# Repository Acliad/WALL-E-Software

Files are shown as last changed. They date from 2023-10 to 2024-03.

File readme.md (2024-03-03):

# Overview
This repo contains code, PCB files, and some 3D files for a WALL-E robot. The robot is controlled by an ESP32 microcontroller with PlayStation Navigation controllers. 3D files can be found under the `Mechanical` folder. The PCB files can be found under the `PCB Files`. The code can be found under the `src` folder. 

This readme file contains information on setting up and using WALL-E, and there are several videos in the `Docs` folder that give examples.

The code is written as an Arduino sketch, but has many C++ files and classes. The custom library code is located in the `src` folder of the walle sketch and is organized into the following folders:
- `audio`: Contains the code for the audio player.
- `display`: Contains the code for the display and animations.
- `motion`: Contains the code for the motion animations.
- `button`: Contains the code for the button handling.
- `controller`: Contains the code for the controller handling.
- `stats`: Contains a simple stats class mostly used for debugging.

Additionally, the root of the `src` folder contains the main sketch file, `walle.ino`, which is the entry point for the program. It also contains several files to help configure WALL-E:
- `config.hpp`: Contains the configuration for the audio player, display, and controller.
- `display_animations.hpp` and `display_animations.cpp`: Contains code for programatically defining display animations.
- `motion_animations.hpp` and `motion_animations.cpp`: Contains code for programatically defining motion animations.

# Button Mapping
This image can be found in `Docs/Images`.

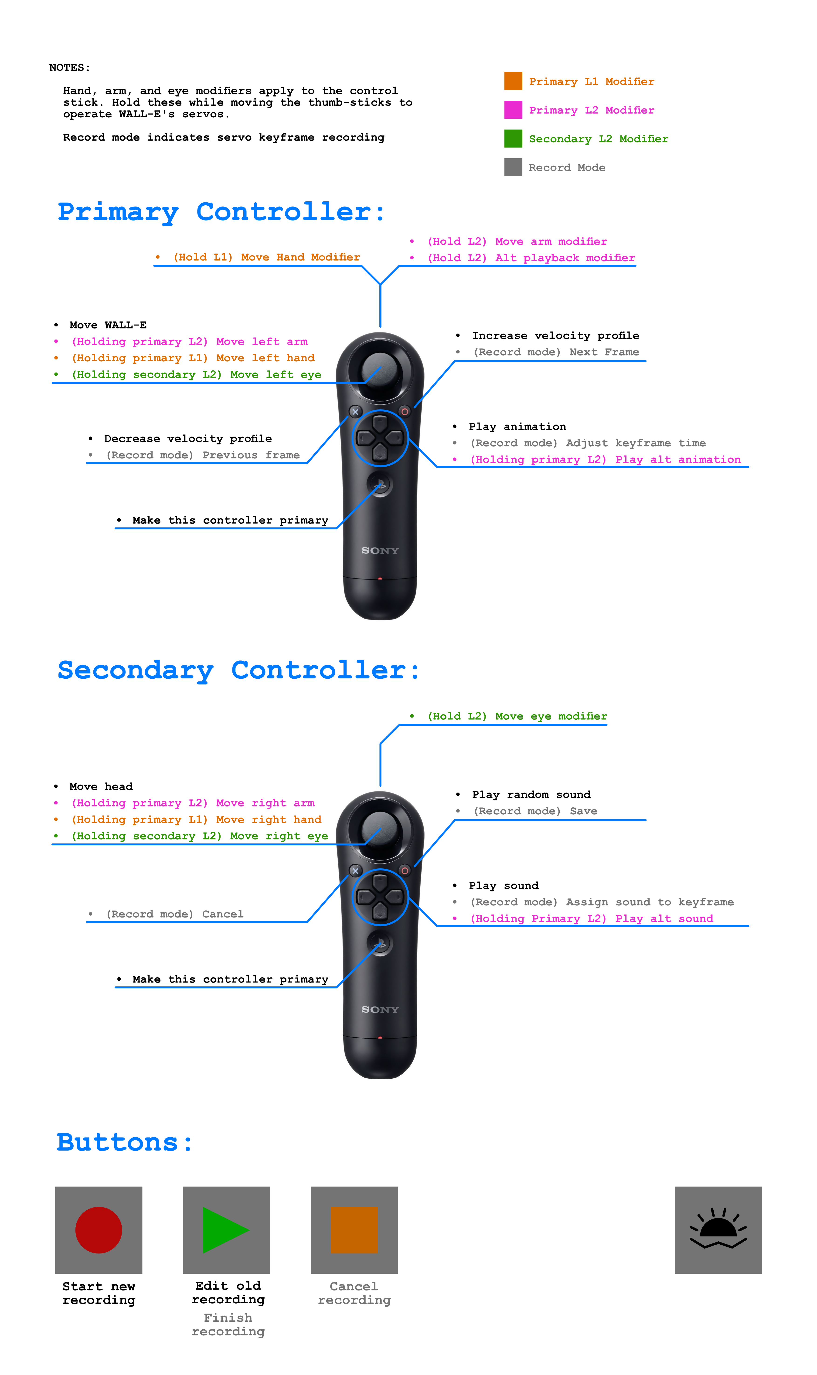
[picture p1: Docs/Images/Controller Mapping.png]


# Setting up Arduino IDE
This project uses a special board package for the ESP32 called [Bluepad32](https://github.com/ricardoquesada/bluepad32). To install it, you need to add this board to your Arduino IDE. The abreviated steps to do this are below. See [this doc page](https://bluepad32.readthedocs.io/en/latest/plat_arduino/) for more detailed instructions.
1. Open the Arduino IDE settings and add the following two URLs to the "Additional Boards Manager URLs" field: 
`https://raw.githubusercontent.com/espressif/arduino-esp32/gh-pages/package_esp32_index.json`
`https://raw.githubusercontent.com/ricardoquesada/esp32-arduino-lib-builder/master/bluepad32_files/package_esp32_bluepad32_index.json`
2. Install the ESP32 and ESP32 Bluepad32 boards from the Boards Manager.
3. Select the `ESP32-WROOM-DA Module` from the Tools > Board > esp32_bluepad32 menu.

You will also need to install the following libraries:
- Adafruit PWM Servo Driver Library
- DFPlayer Mini Mp3 by Makuna
- Ramp
- ServoESP32
- TFT_eSPI

You will need to setup the TFT_eSPI library with the correct config. To do this, create a `TFT_eSPI_Setups` folder in your Arduino libraries folder (usualy in `~/Documents/Arduino/libraries/`), then copy the `TFT_eSPI_walle_setup.h` file in `src/display/` to this new folder. After that, open User_Setup_Select.h in the `/TFT_eSPI/` library folder and comment out the current user config (`User_Setup.h` by default), then add the following line:
```cpp
 #include <../TFT_eSPI_Setups/TFT_eSPI_walle_setup.h>
 ```

After this, you should be able to compile and upload the code to the ESP32. Make sure WALL-E is powered on before plugging in the USB cable to the ESP32, otherwise the USB port will attempt to power the servo motors and will likely trip your USB port's overcurrent protection.

Note that the Arduino IDE will throw some warnings related to "converting a string constant to 'char*'" as well as some bluepad and eSPI_TFT warnings. These can be ignored.

# Adding new sounds
New sounds can be added to the audio player's SD card as `.mp3` files. Audio tracks must be labeled as numbers with the format `0001.mp3`, `0002.mp3`, etc. The number of the audio track is the index that will be used to play the sound. You can configure the audio player sounds and keybindings in the `config.hpp` file. Here is what the folder structure on the SD card should look like:

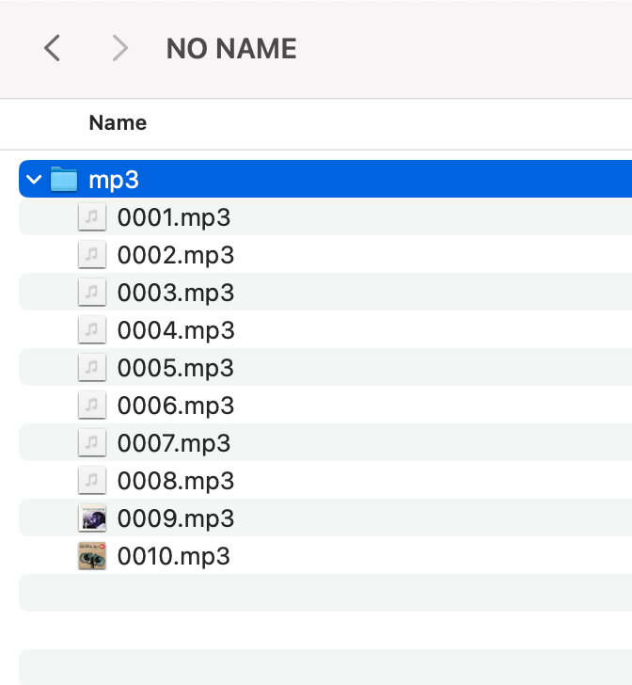
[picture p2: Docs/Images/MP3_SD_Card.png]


For instance, if you add a track `0011.mp3` and you wish to bind it to the `L2 + Up` button, you would add the following line to the `config.hpp` file:
```cpp
const int audio_track_selection_list[] = {
    TRACK_INDEX_EVE_1, // Up
    TRACK_INDEX_TADA, // Right
    TRACK_INDEX_SCREAM, // Down
    TRACK_INDEX_WALLE_1, // Left
    11, // L2 + Up <<<<<<<<<<<<<<<<<<<<<<<< CHANGED TRACK 
    TRACK_INDEX_EVE_3, // L2 + Right
    TRACK_DEFINE_DANCING, // L2 + Down
    TRACK_LA_VIE_EN_ROSE, // L2 + Left
};
```

Sounds which are bound to a button can be added to keyframes in motion animations. 

Similarly, you could add it to the audio_track_random_list. 

```cpp
// Tracks in this array will be selected randomly by the playRandomTrack() function
const int audio_track_random_list[] = {
    TRACK_INDEX_EVE_1,
    TRACK_INDEX_EVE_2,
    TRACK_INDEX_EVE_3,
    TRACK_INDEX_WALLE_1,
    TRACK_INDEX_SCREAM,
    TRACK_INDEX_TADA,
    11 // <<<<<<<<<<<<<<<<<<<<<<<< ADDED TRACK
};
```

# Adding solar animations
The steps to add a solar animation are as follows:
1. Declare your variable name in display_animations.hpp:
```cpp
extern AnimateLeve animate_display_startup;
...
// Add your variable name here
extern AnimateLevel my_animation;
```
2. Define your vairable in display_animations.cpp:
```cpp
AnimateLevel animate_display_startup = AnimateLevel();
...
// Define your variable here
AnimateLevel my_animation = AnimateLevel();
```
3. Create a setup_my_animation() function in display_animations.cpp:
```cpp
void setup_my_animation() {
  my_animation.addKeyframe(0, 0);
  my_animation.addKeyframe(1000, 1);
  ...
}
```
4. Add your setup_my_animation() function to the setup_animations() function in display_animations.cpp:
```cpp
void setup_animations() {
  setup_startup();
  ...
  // Add your setup_my_animation() function here
  setup_my_animation();
}
```

Now your variable ```my_animation``` will be available to use in the main sketch. 

### Notes
- A keyframe with a single change will perform that change at the beginning of the keyframe. For example, if 2 bars are on and you request 3 to be on with a duration of 1 second, the 3rd bar will turn on immediately and the keyframe will wait for 1 second to complete. If you have two or more changes in a keyframe, the changes will be evenly distributed throughout the duration of the keyframe, ending with a change. For example, if 2 bars are on and you request 5 to be on with a duration of 1 second, the 3rd bar will turn on immediately, the 4th bar will turn on after 0.5 seconds, and the 5th bar will turn on after 1 second.
- The sun's status is always evaluated at the beginning of a keyframe.

# Adding motion animations
The steps to add a motion animation are as follows:
1. Declare your variable name in motion_animations.hpp:
```cpp
namespace MotionAnimations {
    // Add custom animations here:
    extern ServoAnimation my_animation;

    // Rest of namespace ...
}
```
2. Define your vairable in motion_animations.cpp:
```cpp
namespace MotionAnimations {
    // Define new animations here

    ServoAnimation my_animation = ServoAnimation();

    // Rest of namespace ...
}
```
3. Create a setup_my_animation() function in motion_animations.cpp. Keyframes are created one at a time and then added to the previously created animation. Create a keyframe with `ServoKeyframe *my_keyframe = new ServoKeyframe(duration_ms);`. Add the servo positions to the keyframe with `my_keyframe->add_servo_scaler(servo_ptr, position);`. Add the keyframe to the animation with `my_animation.addKeyframe(my_keyframe);`. Servos are addressed by their name. There is a #define for each servo. E.g, to get the left eye servo you would use `servos.map[SERVO_EYE_LEFT_NAME]` For example:
```cpp
// Create setup functions for each animation.
// NOTE: Don't forget to call these functions in setup_animations().
void setup_my_animation() {
    // Rotate eyes in opposite directions
    ServoKeyframe *my_keyframe1 = new ServoKeyframe(1000);
    my_keyframe->add_servo_scaler(servos.map[SERVO_EYE_LEFT_NAME], 0.75);
    my_keyframe->add_servo_scaler(servos.map[SERVO_EYE_RIGHT_NAME], -0.75);
    
    // Pause for 3 seconds
    ServoKeyframe *my_keyframe2 = new ServoKeyframe(3000);

    // Return the eyes to their original position
    ServoKeyframe *my_keyframe3 = new ServoKeyframe(1000);
    my_keyframe->add_servo_scaler(servos.map[SERVO_EYE_LEFT_NAME], 0);
    my_keyframe->add_servo_scaler(servos.map[SERVO_EYE_RIGHT_NAME], 0);

    // Add the keyframes to the animation
    my_animation.add_keyframe(my_keyframe1);
    my_animation.add_keyframe(my_keyframe2);
    my_animation.add_keyframe(my_keyframe3);
}
```
4. Add your setup_my_animation() function to the setup_animations() function in motion_animations.cpp:
```cpp
void setup_animations(ServoContext servos) {
    // This function should get called in the main setup() function. It calls all animation setup functions for use in
    // the main sketch.

    // Add setup functions for new animations here
    setup_my_animation();

    // Rest of animation setups...
}
```
5. Play the animation with `servo_player.play(&MotionAnimations::my_animation);`. Alternatively, you can add the animation to the `head_animations` array in the main sketch to bind it to a button press:
```cpp
ServoAnimation         *head_animations[] = {
    &MotionAnimations::my_animation, // Up
    nullptr,      // Right
    nullptr,      // Down
    nullptr,      // Left
    nullptr,      // L2 + Up
    nullptr,      // L2 + Right
    nullptr,      // L2 + Down
    nullptr       // L2 + Left
};
```

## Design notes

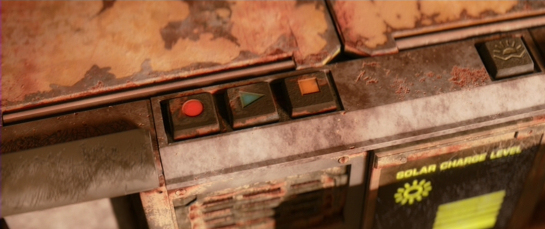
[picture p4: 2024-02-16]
Docs/References/Buttons Reference.jpeg

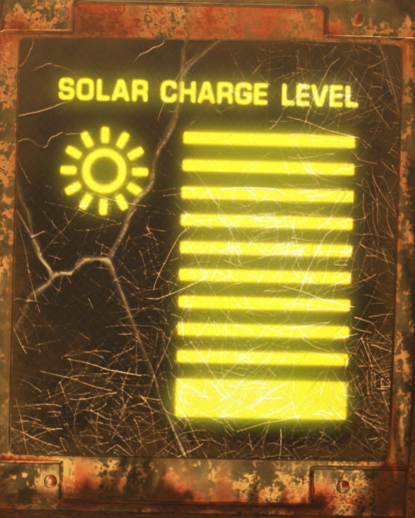
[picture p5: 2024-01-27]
Docs/References/Solar Reference.png

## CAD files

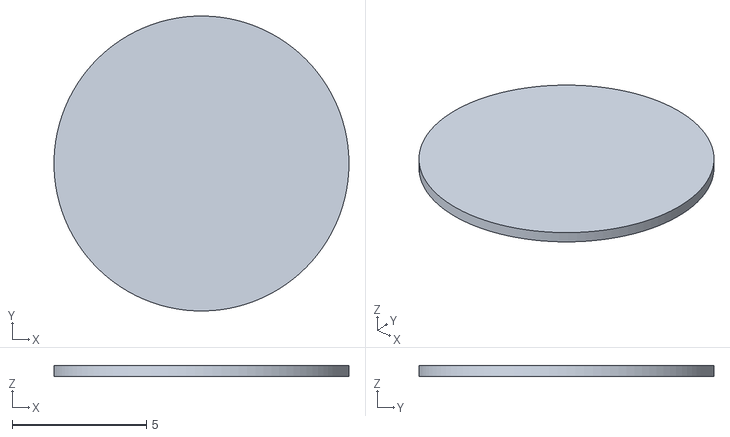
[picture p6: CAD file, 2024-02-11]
Mechanical/Buttons/Meshes/Record Insert.stl
11.0 x 11.0 x 0.4

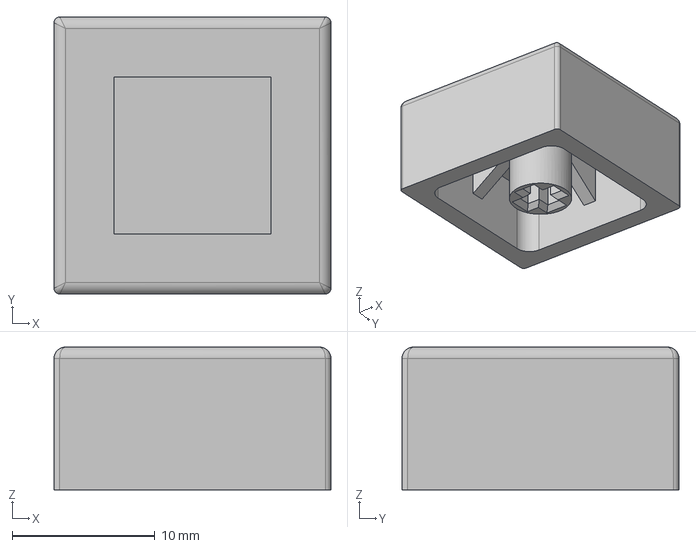
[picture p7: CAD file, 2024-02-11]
Mechanical/Buttons/Solids/Stop Button.stp
19.4 x 19.4 x 10.0 mm

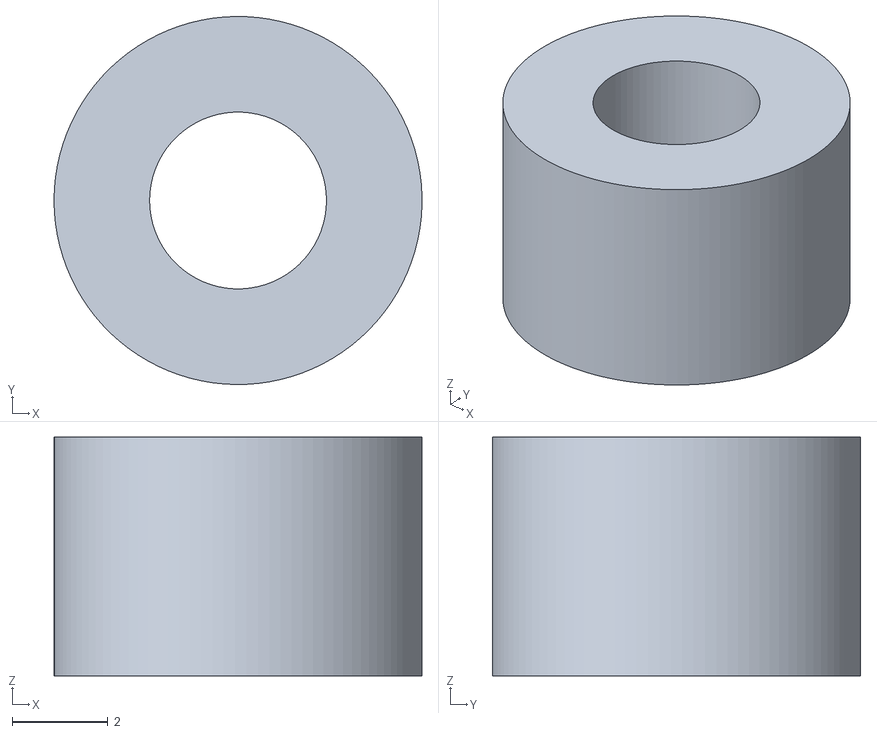
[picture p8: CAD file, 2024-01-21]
Mechanical/Carrier Board Standoff/Meshes/Carrier Board Standoff.stl
7.70 x 7.70 x 5.00

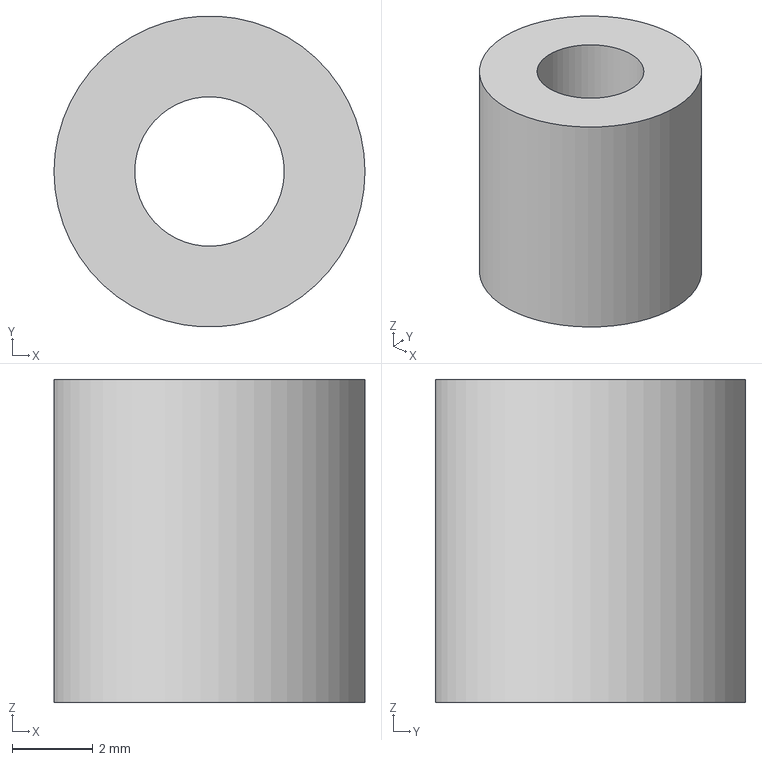
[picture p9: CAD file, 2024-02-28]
Mechanical/Carrier Board Standoff/Solids/Carrier Board Standoff.stp
7.70 x 7.69 x 8.00 mm

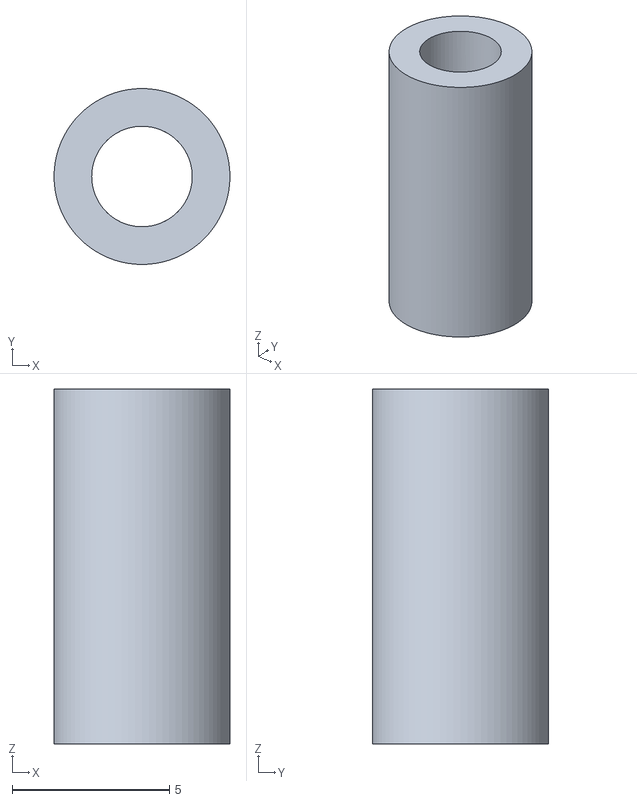
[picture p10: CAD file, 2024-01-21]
Mechanical/PWM Module Spacer/Meshes/PWM Module Spacer.stl
5.60 x 5.60 x 11.3

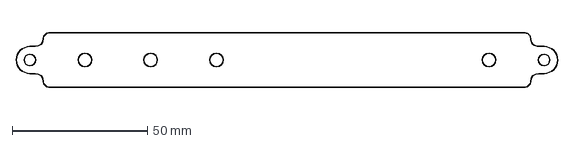
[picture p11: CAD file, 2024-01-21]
PCB Files/WALL-E Button Board/Mechanical/Board Outline.dxf
200.0 x 20.0 mm

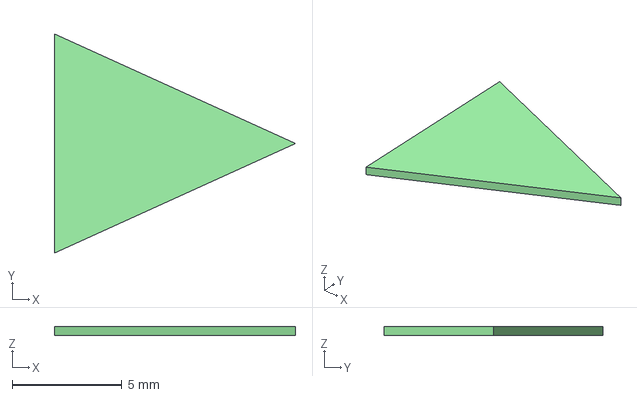
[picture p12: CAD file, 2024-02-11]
Mechanical/Buttons/Solids/Play Insert.stp
11.0 x 10.0 x 0.4 mm

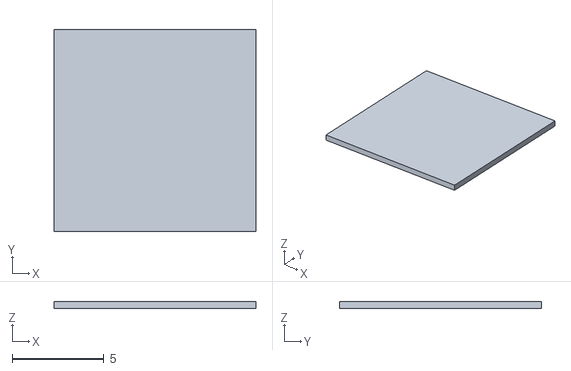
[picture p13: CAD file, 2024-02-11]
Mechanical/Buttons/Meshes/Stop Insert.stl
11.0 x 11.0 x 0.4

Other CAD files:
Mechanical/PWM Module Spacer/Solids/PWM Module Spacer.stp
Mechanical/Buttons/Meshes/Play Button.stl
Mechanical/Buttons/Meshes/Stop Button.stl
Mechanical/Buttons/Solids/Record Insert.stp
Mechanical/Buttons/Meshes/Record Button.stl
Mechanical/Buttons/Solids/Play Button.stp
Mechanical/Buttons/Meshes/Play Insert.stl
Mechanical/Buttons/Solids/Record Button.stp
Mechanical/Buttons/Solids/Stop Insert.stp
Mechanical/Buttons/Meshes/Sun Button.stl
Mechanical/Buttons/Solids/Sun Button.stp

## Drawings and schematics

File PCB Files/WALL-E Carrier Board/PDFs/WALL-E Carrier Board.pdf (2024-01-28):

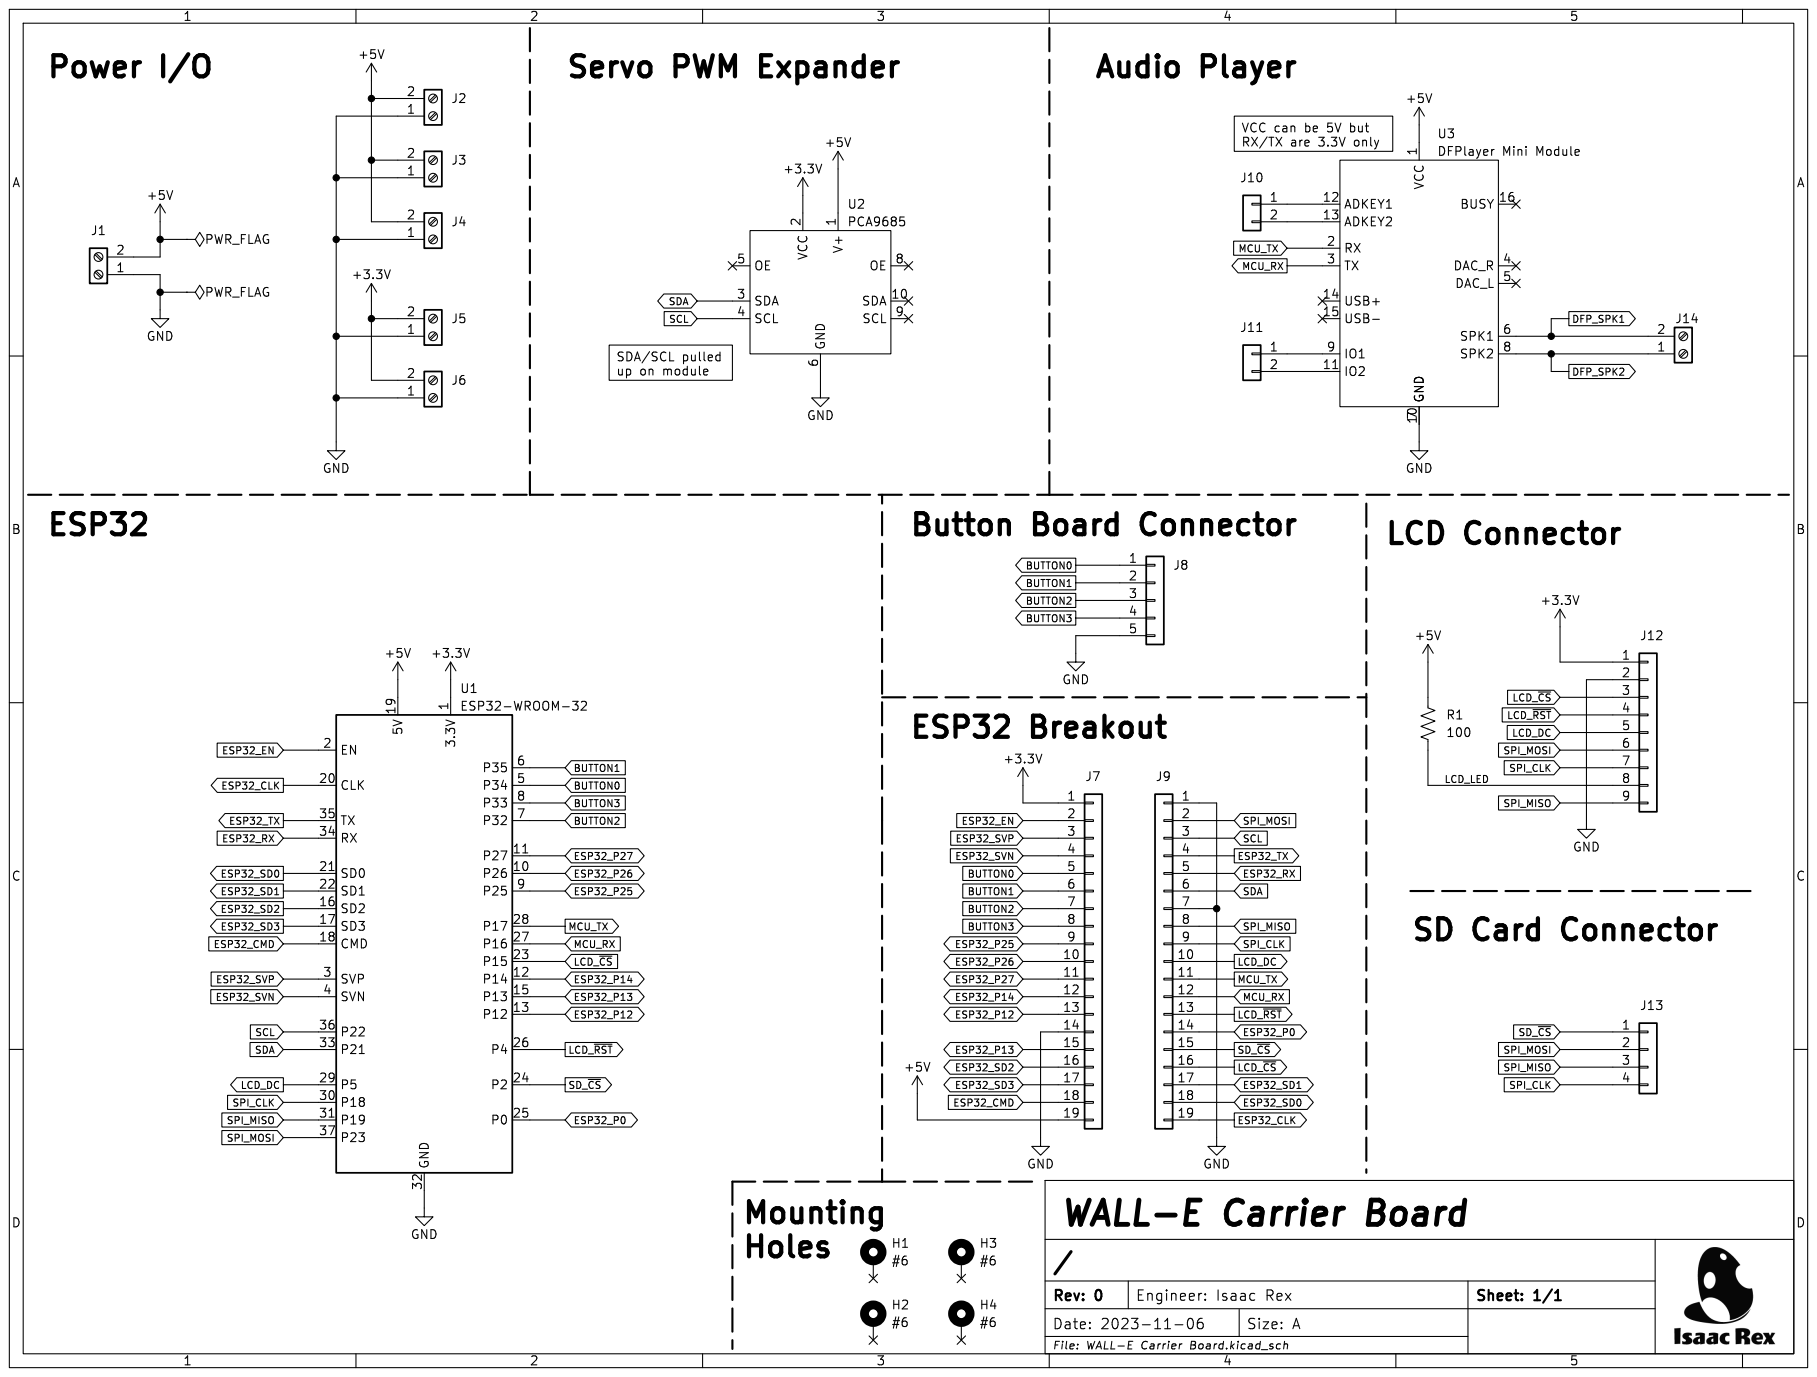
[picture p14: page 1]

VCC can be 5V but RX/TX are 3.3V only SDA/SCL pulled

2 SDA 3 SCL 4 OE 5 GND

1 P26 10 P27 11 P14 12 P12 13 P13 15 SD2 16 SD3 17 CMD 18 5V 19 EN 2 CLK 20 SD0 21 SD1 22 P15 23 P2 24 P0 25 P4 26 P16 27 P17 28 P5 29 SVP 3 P18 30 P19 31 GND 32 P21 33 RX 34 TX 35 P22 36 P23 37 SVN 4 P34 5 P35 6 P32 7 P33 8 P25 9 U1ESP32-WROOM-32

File: WALL-E Carrier Board.kicad_sch WALL-E Carrier Board

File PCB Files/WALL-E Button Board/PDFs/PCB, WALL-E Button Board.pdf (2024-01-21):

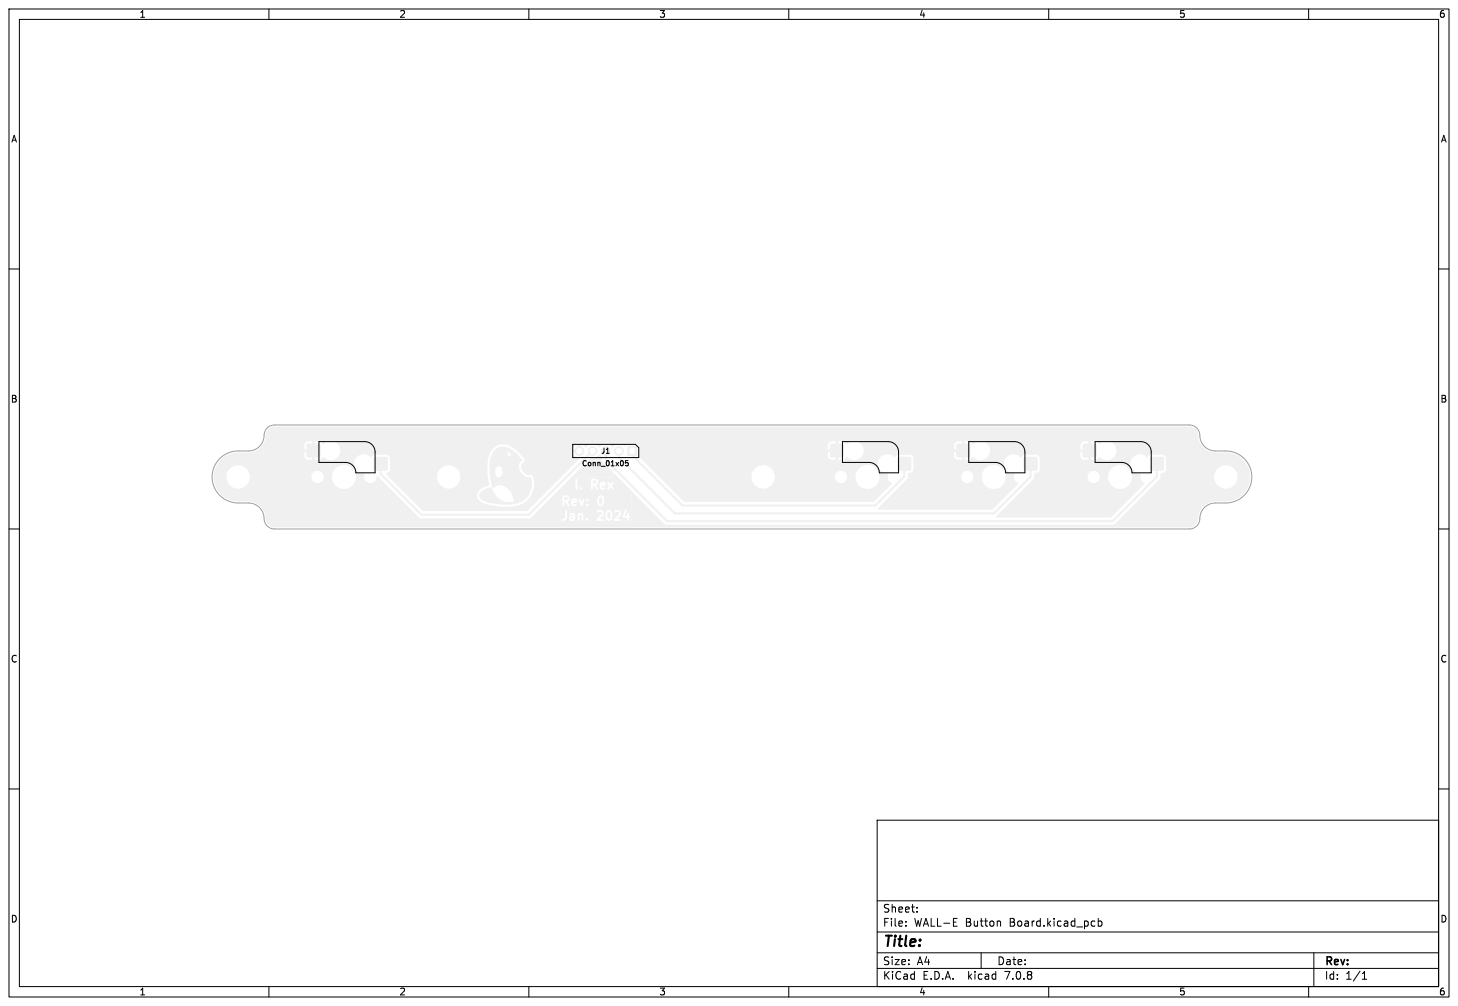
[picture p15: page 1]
D Date: KiCad; kicad; 7.0.8 Size: A4; Rev:; Id: 1/1 Title: File: WALL-E; Button; Board.kicad_pcb Sheet:

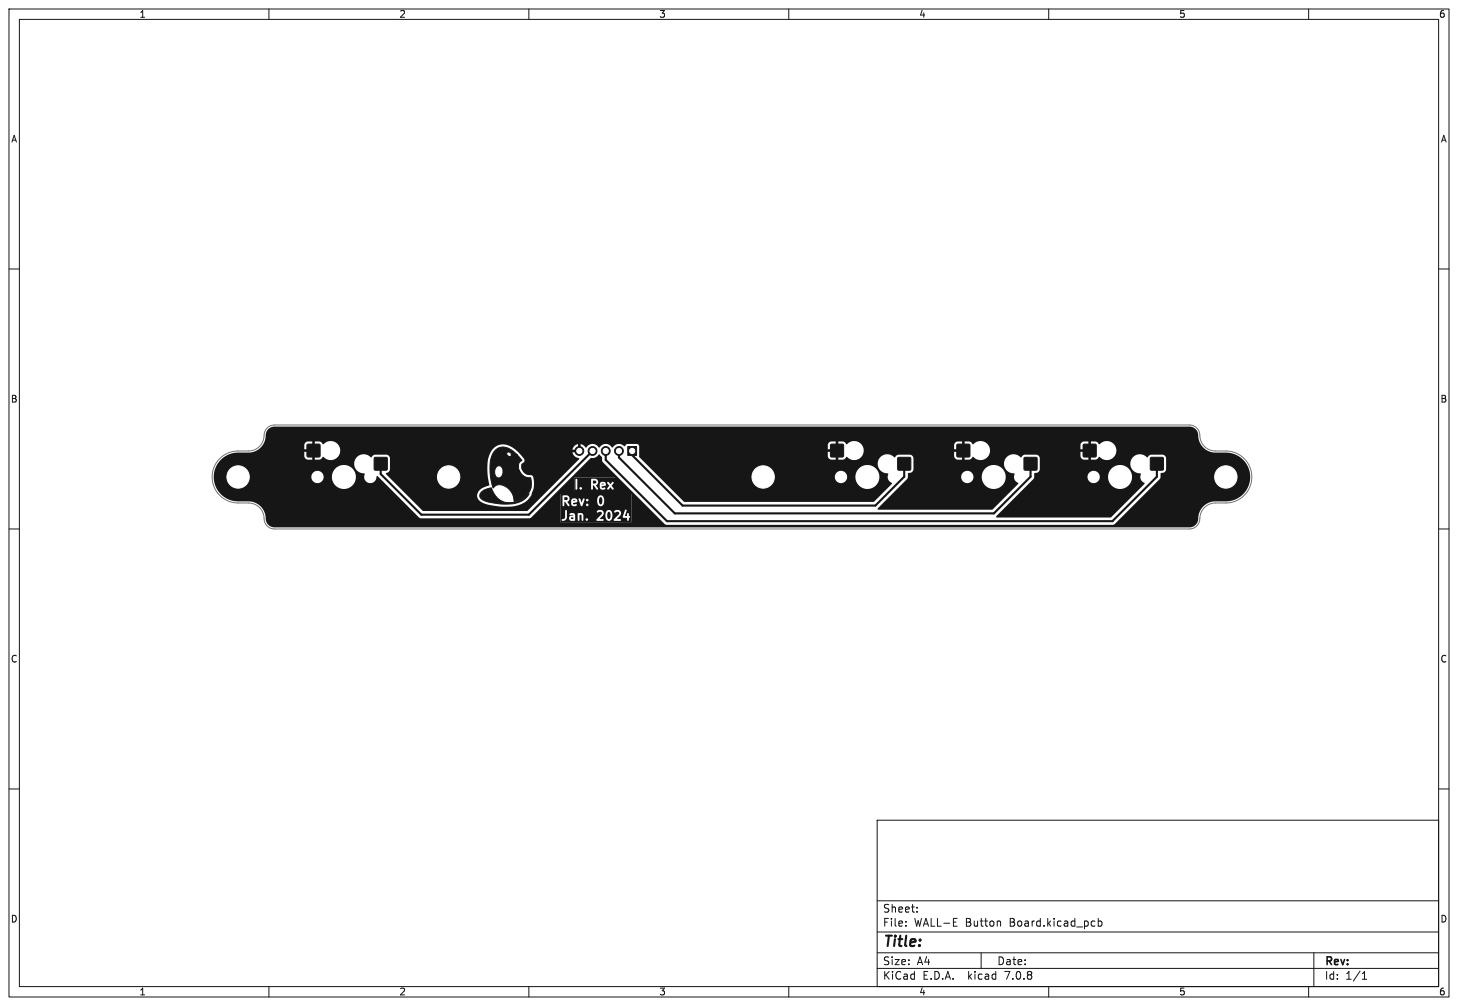
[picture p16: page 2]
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

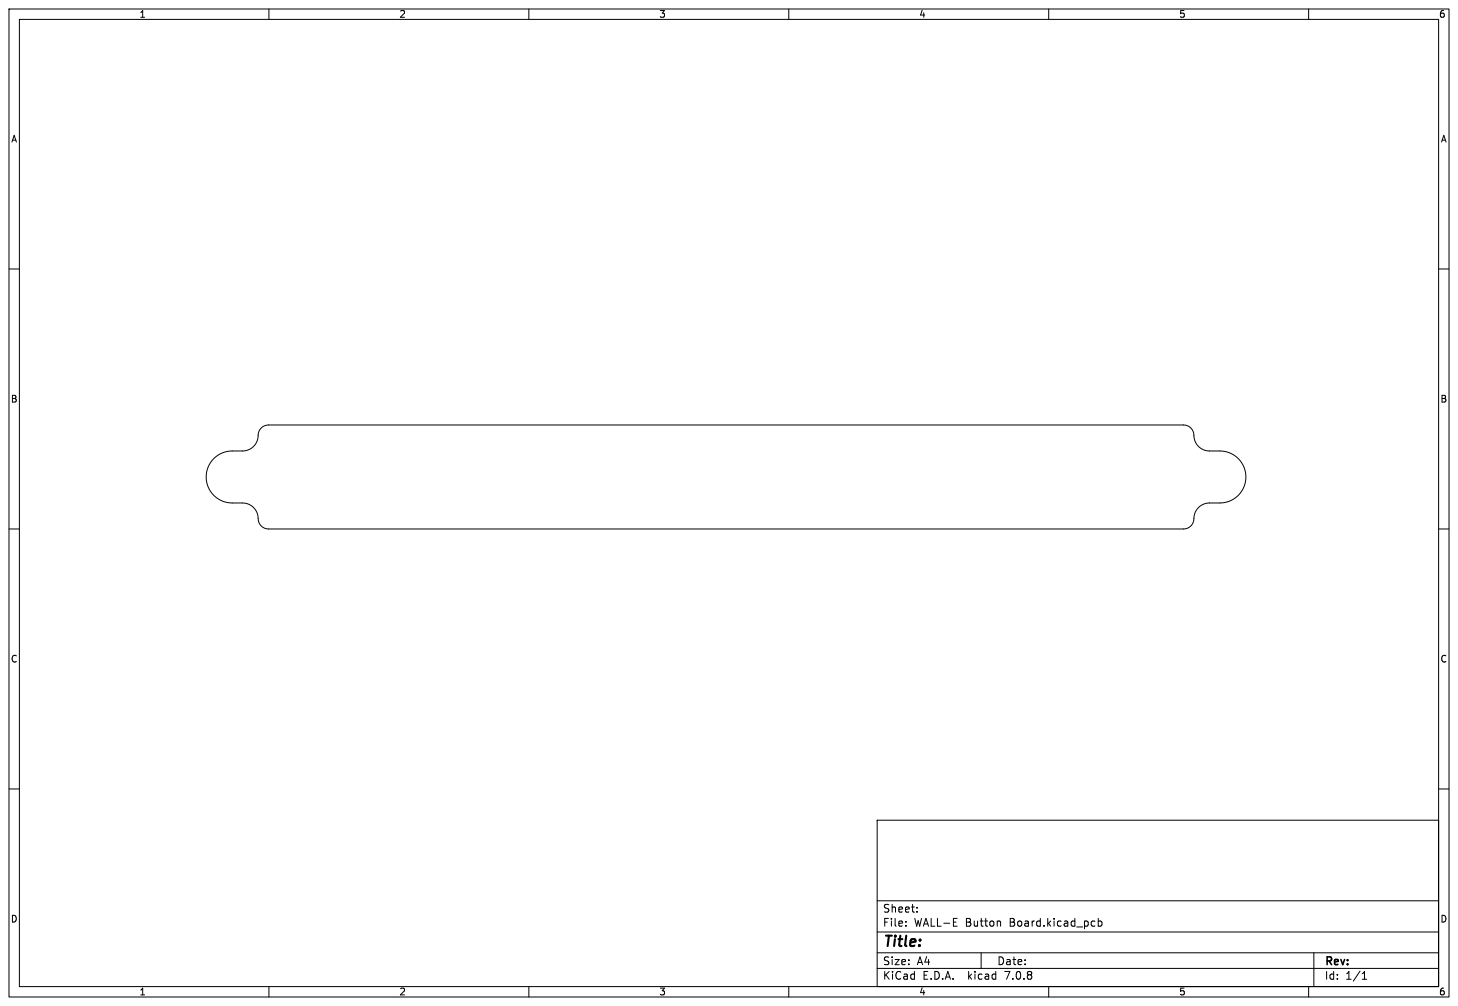
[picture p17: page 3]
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

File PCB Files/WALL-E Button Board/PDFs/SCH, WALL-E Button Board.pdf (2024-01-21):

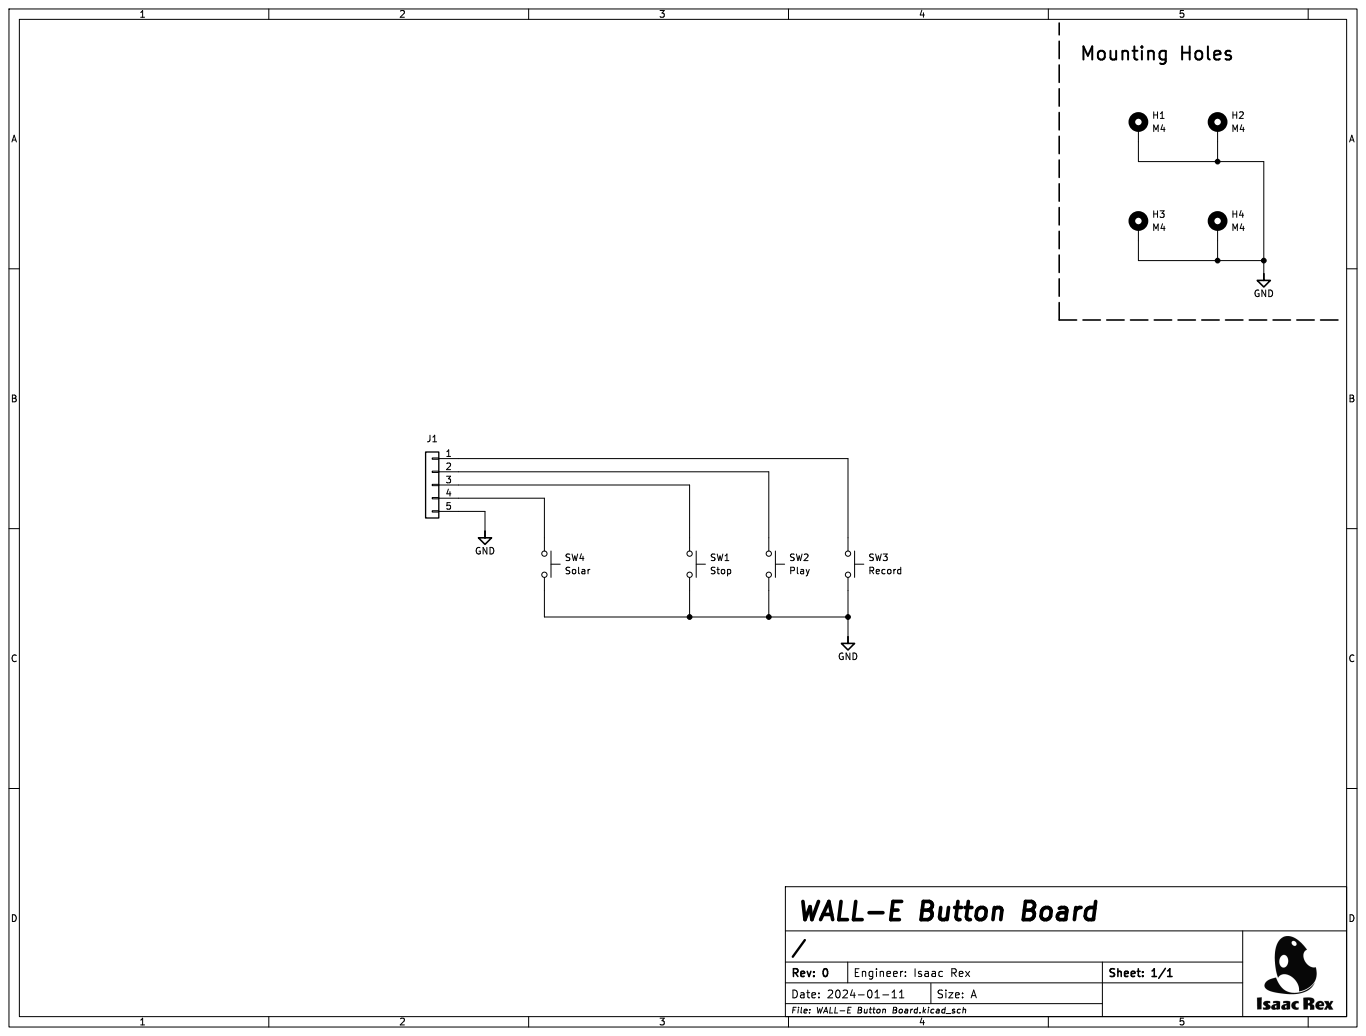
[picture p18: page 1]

File: WALL-E Button Board.kicad_sch WALL-E Button Board

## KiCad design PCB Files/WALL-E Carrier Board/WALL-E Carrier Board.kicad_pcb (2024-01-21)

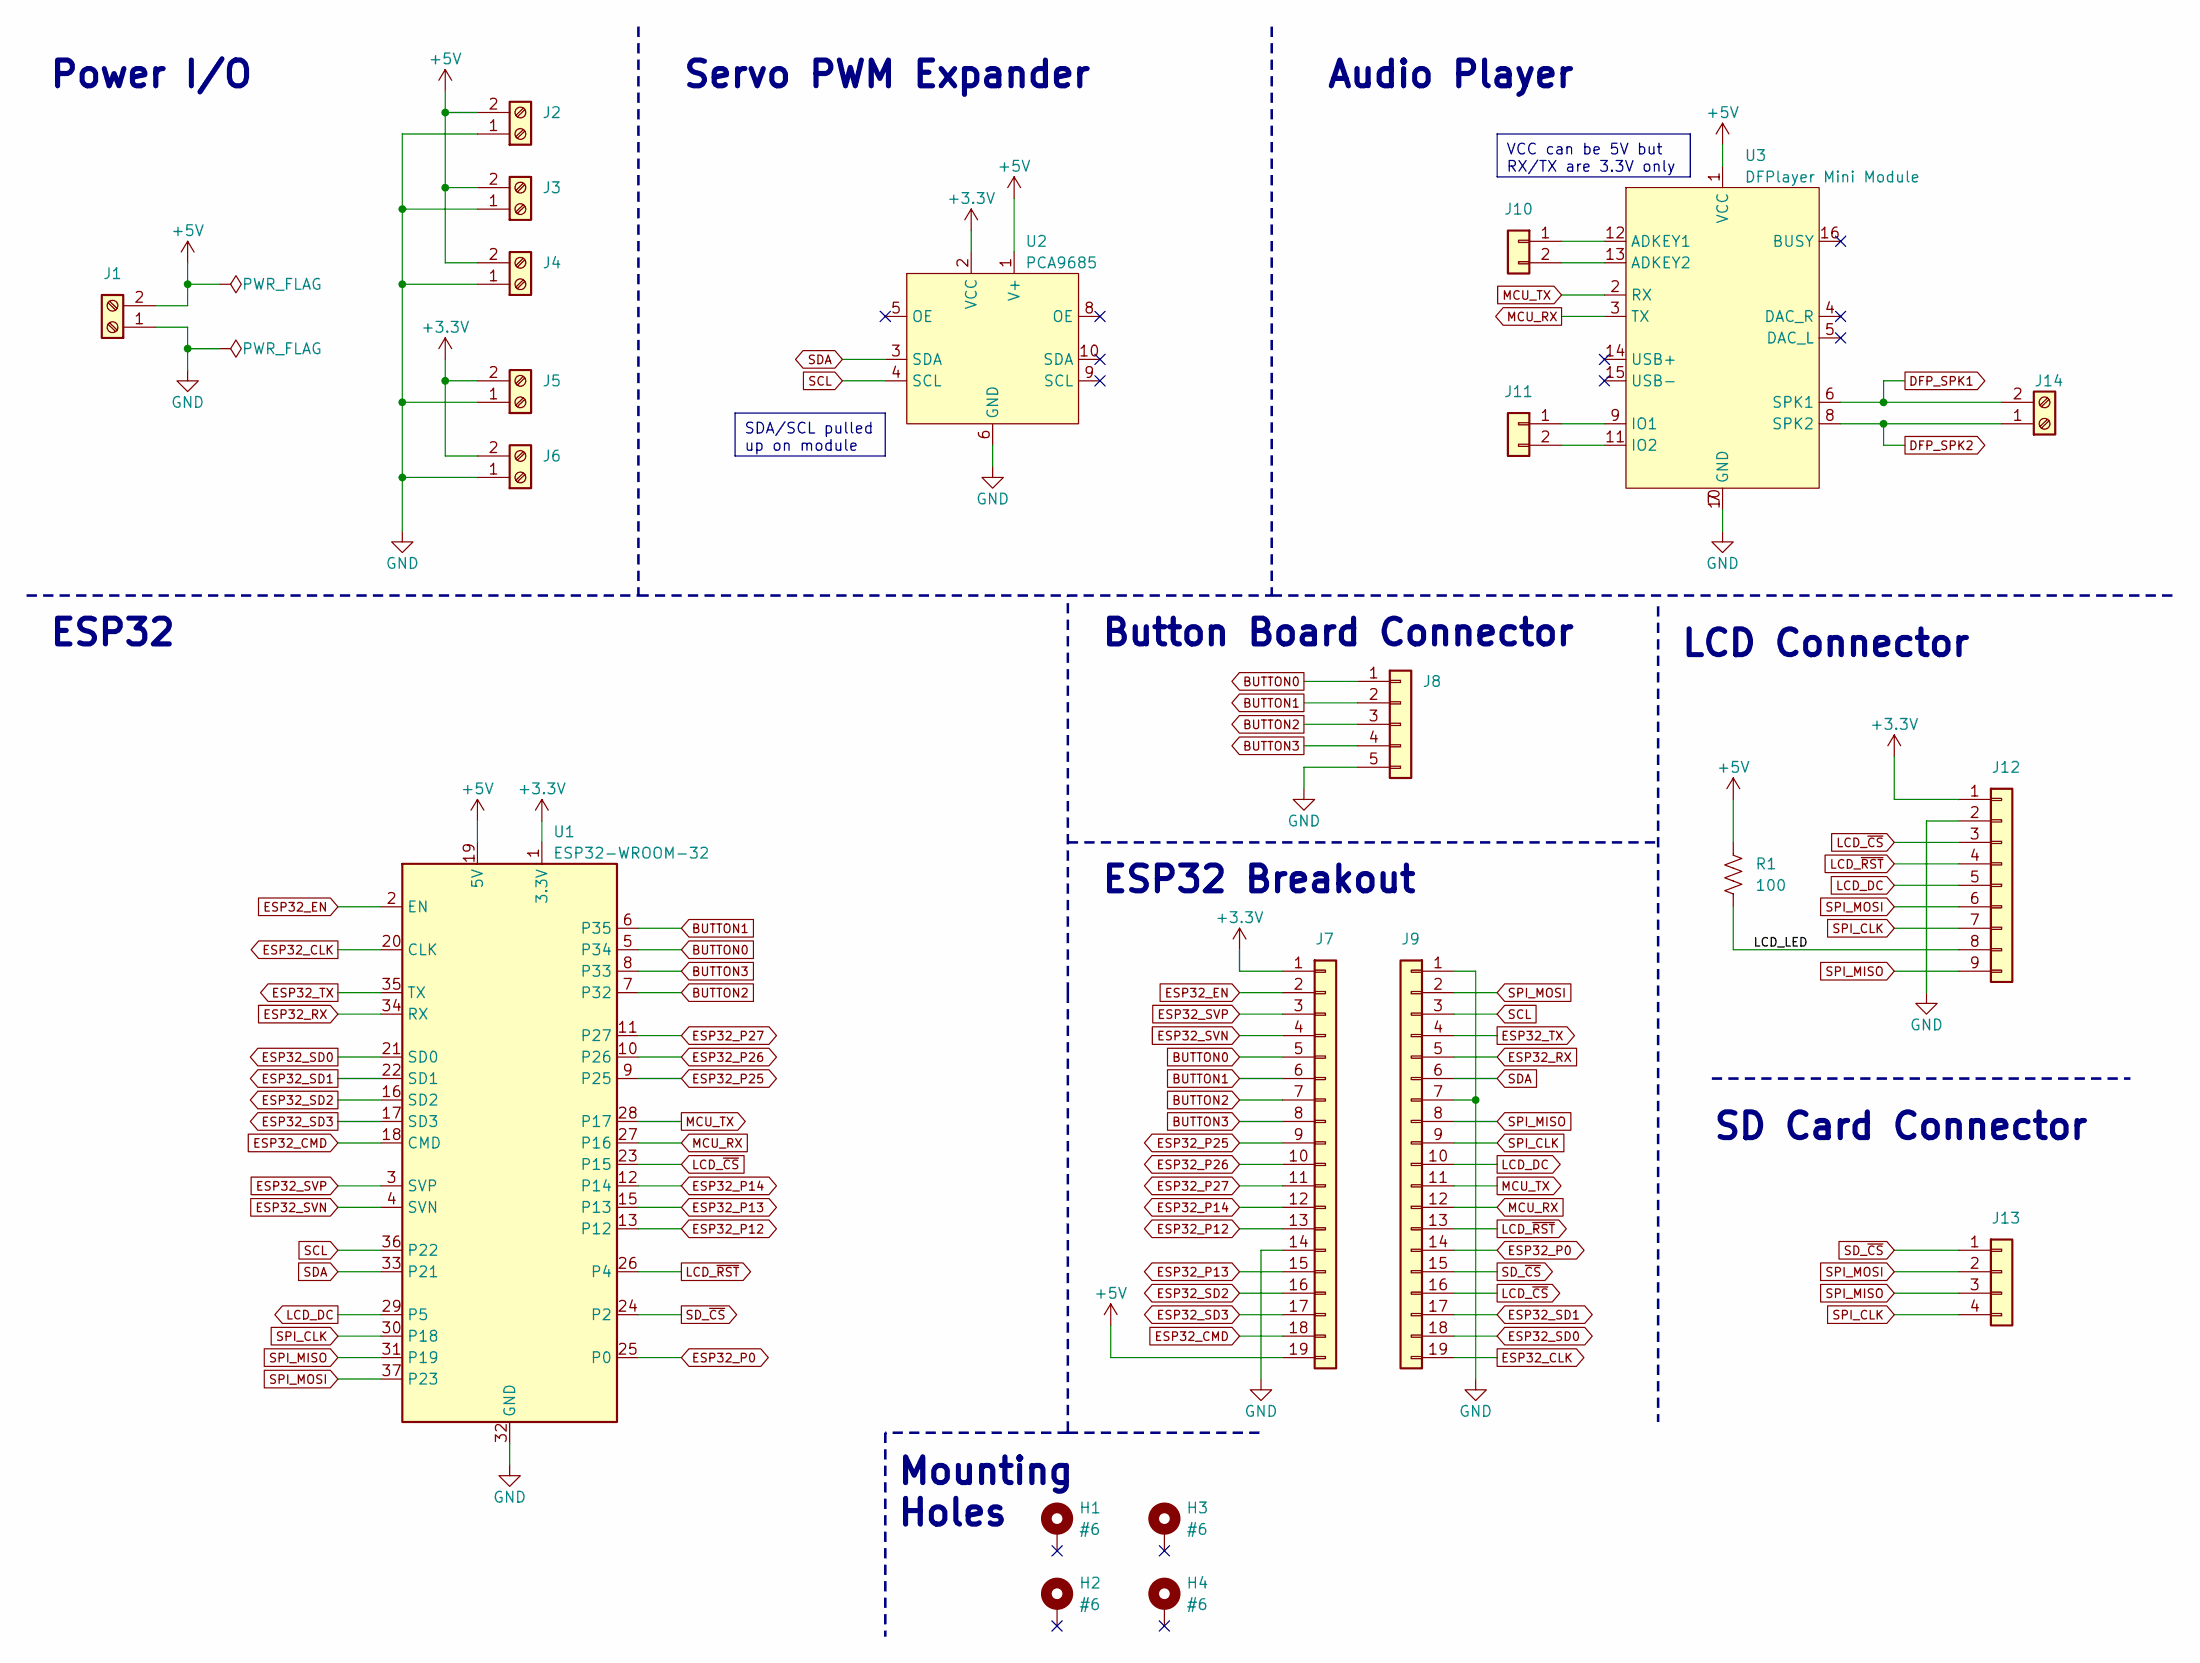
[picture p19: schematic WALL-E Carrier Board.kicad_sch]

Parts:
H1, H2, H3, H4: #6; MountingHole_3.7mm_Pad
J1, J2, J3, J4, J5, J6, J14: Screw_Terminal_01x02; TerminalBlock_MetzConnect_Type011_RT05502HBWC_1x02_P5.00mm_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
J7, J9: Conn_01x19; PinHeader_1x19_P2.54mm_Vertical
J8: Conn_01x05; PinHeader_1x05_P2.54mm_Vertical
J10, J11: Conn_01x02; PinHeader_1x02_P2.54mm_Vertical
J12: Conn_01x09; PinHeader_1x09_P2.54mm_Vertical
J13: Conn_01x04; PinHeader_1x04_P2.54mm_Vertical
R1: 100; R_Axial_DIN0207_L6.3mm_D2.5mm_P10.16mm_Horizontal
U1: ESP32-WROOM-32; HiLetgo ESP-32S Module
U2: PCA9685; Adafruit PCA9685 rev C
U3: DFPlayer Mini Module

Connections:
+3.3V: J5.2, J6.2, J7.1, J12.1, U1.1 (3.3V), U2.2 (VCC), U2.11 (VCC)
+5V: J1.2, J2.2, J3.2, J4.2, J7.19, R1.1, U1.19 (5V), U2.1 (V+), U2.12 (V+), U3.1 (VCC)
/LCD_LED: J12.8, R1.2
BUTTON0: J7.5, J8.1, U1.5 (P34)
BUTTON1: J7.6, J8.2, U1.6 (P35)
BUTTON2: J7.7, J8.3, U1.7 (P32)
BUTTON3: J7.8, J8.4, U1.8 (P33)
DFP_SPK1: J14.2, U3.6 (SPK1)
DFP_SPK2: J14.1, U3.8 (SPK2)
ESP32_CLK: J9.19, U1.20 (CLK)
ESP32_CMD: J7.18, U1.18 (CMD)
ESP32_EN: J7.2, U1.2 (EN)
ESP32_P0: J9.14, U1.25 (P0)
ESP32_P12: J7.13, U1.13 (P12)
ESP32_P13: J7.15, U1.15 (P13)
ESP32_P14: J7.12, U1.12 (P14)
ESP32_P25: J7.9, U1.9 (P25)
ESP32_P26: J7.10, U1.10 (P26)
ESP32_P27: J7.11, U1.11 (P27)
ESP32_RX: J9.5, U1.34 (RX)
ESP32_SD0: J9.18, U1.21 (SD0)
ESP32_SD1: J9.17, U1.22 (SD1)
ESP32_SD2: J7.16, U1.16 (SD2)
ESP32_SD3: J7.17, U1.17 (SD3)
ESP32_SVN: J7.4, U1.4 (SVN)
ESP32_SVP: J7.3, U1.3 (SVP)
ESP32_TX: J9.4, U1.35 (TX)
GND: J1.1, J2.1, J3.1, J4.1, J5.1, J6.1, J7.14, J8.5, J9.1, J9.7, J12.2, U1.14 (GND), U1.32 (GND), U1.38 (GND), U2.6 (GND), U2.7 (GND), U3.7 (GND), U3.10 (GND)
LCD_DC: J9.10, J12.5, U1.29 (P5)
LCD_~CS: J9.16, J12.3, U1.23 (P15)
LCD_~RST: J9.13, J12.4, U1.26 (P4)
MCU_RX: J9.12, U1.27 (P16), U3.3 (TX)
MCU_TX: J9.11, U1.28 (P17), U3.2 (RX)
unnamed: J10.1, U3.12 (ADKEY1)
unnamed: J10.2, U3.13 (ADKEY2)
unnamed: J11.1, U3.9 (IO1)
unnamed: J11.2, U3.11 (IO2)
SCL: J9.3, U1.36 (P22), U2.4 (SCL)
SDA: J9.6, U1.33 (P21), U2.3 (SDA)
SD_~CS: J9.15, J13.1, U1.24 (P2)
SPI_CLK: J9.9, J12.7, J13.4, U1.30 (P18)
SPI_MISO: J9.8, J12.9, J13.3, U1.31 (P19)
SPI_MOSI: J9.2, J12.6, J13.2, U1.37 (P23)

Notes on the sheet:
VCC can be 5V but RX/TX are 3.3V only
SDA/SCL pulled up on module
SD Card Connector
Mounting Holes
Power I/O
LCD Connector
Audio Player
Servo PWM Expander
ESP32 Breakout
Button Board Connector
ESP32

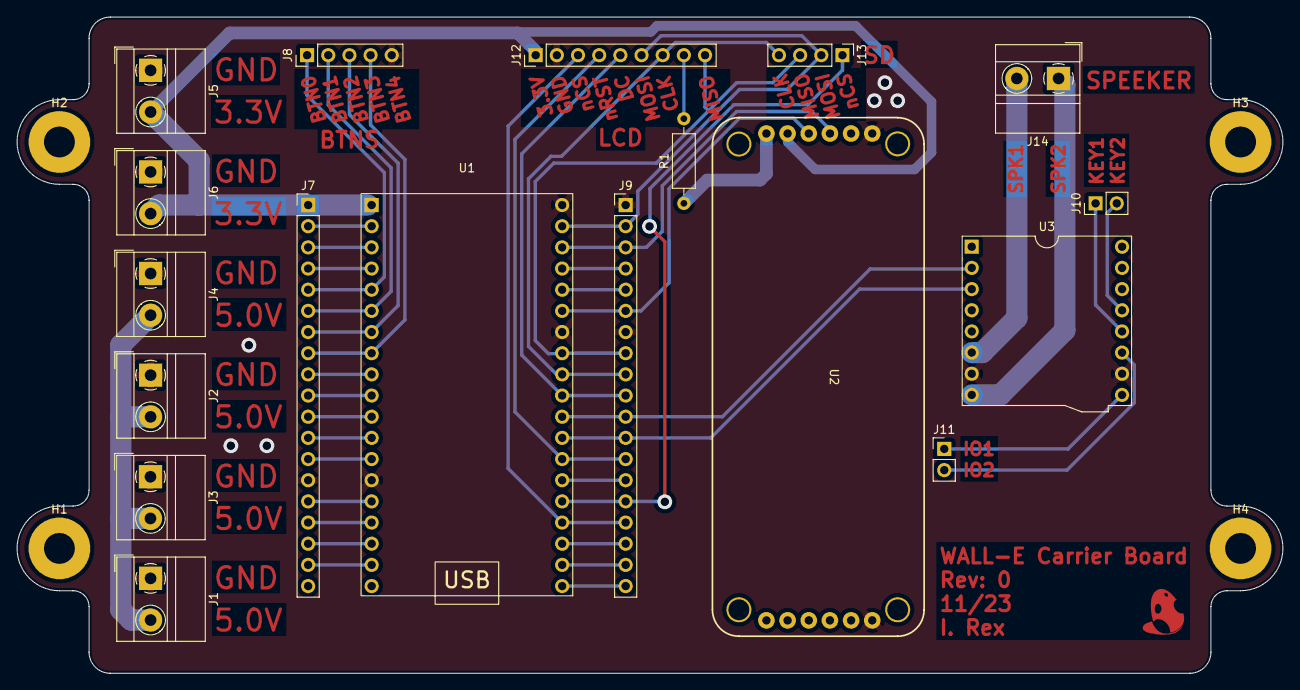
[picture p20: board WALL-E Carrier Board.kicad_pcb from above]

Board: 2 copper layers, 151.9 x 78.7 mm, 22 parts (0 on the bottom side), 43 nets.

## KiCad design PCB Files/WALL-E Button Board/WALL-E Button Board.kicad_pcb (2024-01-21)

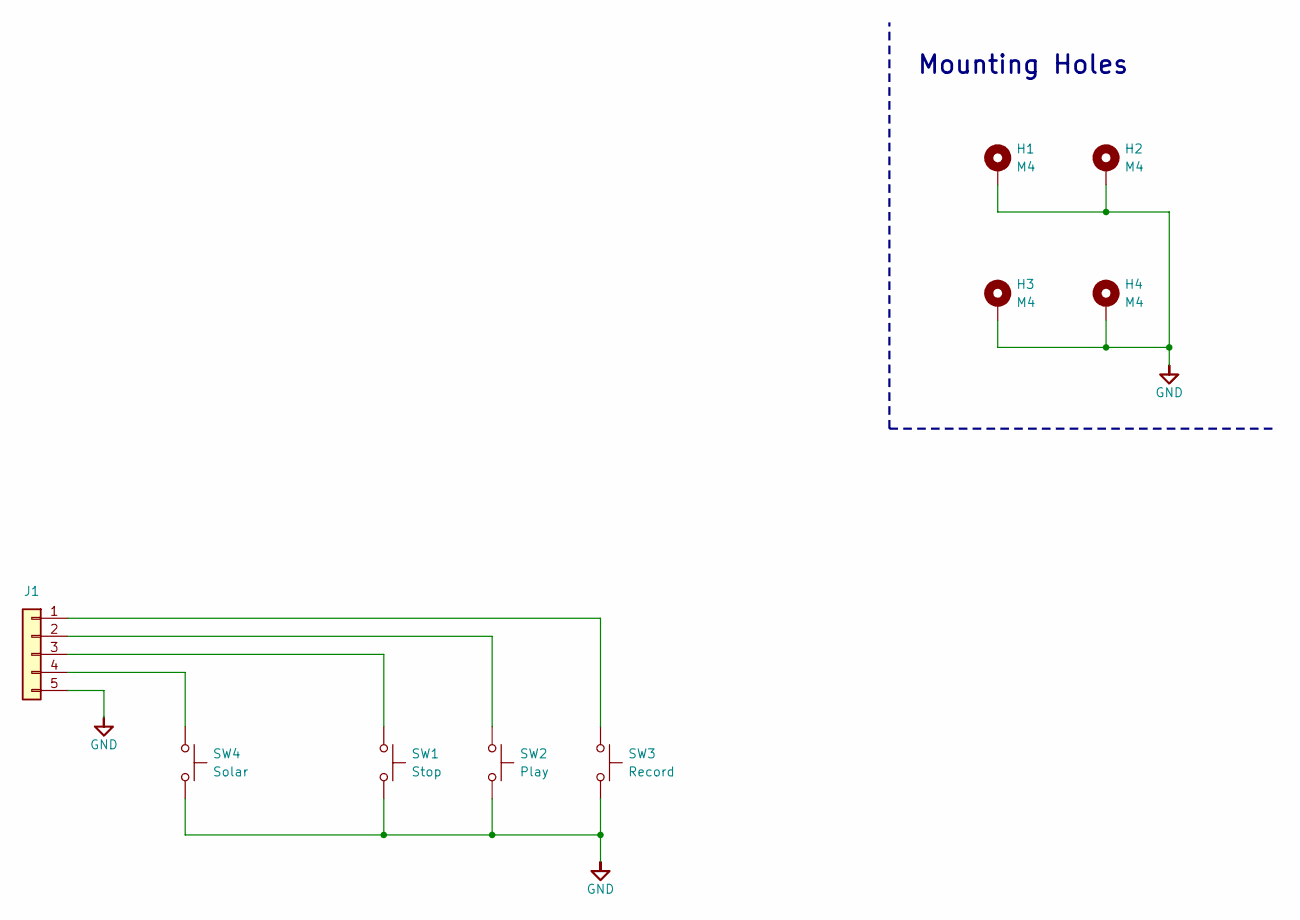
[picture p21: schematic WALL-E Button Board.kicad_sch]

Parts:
H1, H2, H3, H4: M4; MountingHole_4.3mm_M4_DIN965_Pad
J1: Conn_01x05; PinHeader_1x05_P2.54mm_Vertical
SW1: Stop; SW_Hotswap_Kailh_MX
SW2: Play; SW_Hotswap_Kailh_MX
SW3: Record; SW_Hotswap_Kailh_MX
SW4: Solar; SW_Hotswap_Kailh_MX

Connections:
GND: H1.1, H2.1, H3.1, H4.1, J1.5, SW1.2, SW2.2, SW3.2, SW4.2
unnamed: J1.1, SW3.1
unnamed: J1.2, SW2.1
unnamed: J1.3, SW1.1
unnamed: J1.4, SW4.1

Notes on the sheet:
Mounting Holes

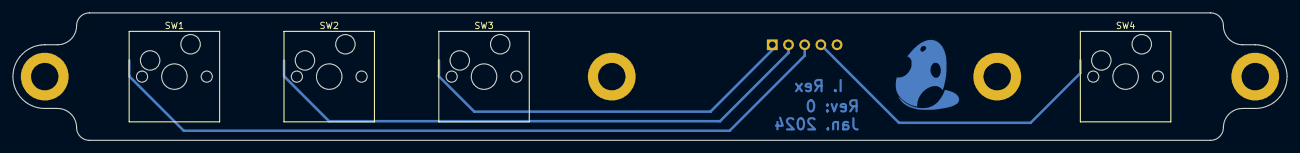
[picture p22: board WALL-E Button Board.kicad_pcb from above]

Board: 2 copper layers, 200.0 x 20.0 mm, 9 parts (1 on the bottom side), 5 nets.

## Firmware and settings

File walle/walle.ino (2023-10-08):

#include <Ps3Controller.h>
#include <Wire.h>
#include <Adafruit_PWMServoDriver.h>
#include <DFMiniMp3.h>
#include "src/motion/motor.hpp"

// #define MOTOR_RIGHT_REVERSE_DIRECTION
// #define MOTOR_LEFT_REVERSE_DIRECTION

// #define ENABLE_AUDIO

#define PCA9685_OSCILLATION_FREQ (25000000) // TODO: Needs to be tuned?
#define SERVO_FREQ_HZ (50) // Analog servos run at ~50 Hz updates

#define DEFAULT_AUDIO_VOLUME (24)
#define STARTUP_TRACK_INDEX (1) // Set to 0 if you don't want to play anything

// Servo/motor indices
#define MOTOR_LEFT_IDX       (0)
#define MOTOR_RIGHT_IDX      (1)
#define SERVO_NECK_YAW_IDX   (15)
#define SERVO_NECK_PTICH_IDX (14)
#define SERVO_EYE_LEFT_IDX   (13)
#define SERVO_EYE_RIGHT_IDX  (12)

#define THUMBSTICK_MAX (127)
#define THUMBSTICK_MIN (-128)
#define TRIGGER_MAX (255)
#define TRIGGER_MIN (0)

#define PI_OVER_FOUR (PI/4.0)

const unsigned int servo_neutral_us = 1500;
const unsigned int servo_min_us = 1000;
const unsigned int servo_max_us = 2000;

const unsigned int motor_range_us = servo_max_us - servo_min_us;
float left_motor_speed = 0.0f;
float right_motor_speed = 0.0f;

int servo_neck_yaw_us   = servo_neutral_us;
int servo_neck_pitch_us = servo_neutral_us;
int servo_eye_left_us   = servo_neutral_us;
int servo_eye_right_us  = servo_neutral_us;

unsigned int motor_ramp_up_time_ms   = 200;
unsigned int motor_ramp_down_time_ms = motor_ramp_up_time_ms;

float motor_speed_factor = 0.5;

// Have to manually track button events as the controller library
// doesn't appear to poll frequently enough to properly capture button
bool circle_pressed_last = false;
bool circle_pressed = false;
bool d_up_pressed_last = false;
bool d_up_pressed = false;
bool d_down_pressed_last = false;
bool d_down_pressed = false;

bool pca9685_connected = false;

DfMp3_Status dfmp3_status;
unsigned int audio_current_track = 0;
unsigned int audio_num_tracks = 1;

// forward declare the notify class, just the name
class Mp3Notify; 
// define a handy type using serial and our notify class
typedef DFMiniMp3<HardwareSerial, Mp3Notify> DfMp3; 

DfMp3 dfmp3 = DfMp3(Serial2);
Adafruit_PWMServoDriver pca9685 = Adafruit_PWMServoDriver();
// NOTE: The motor constructor assumes the PCA9685 has already been initialized
Motor motor_r = Motor(&pca9685, MOTOR_RIGHT_IDX);
Motor motor_l = Motor(&pca9685, MOTOR_LEFT_IDX);

// Function prototypes
void map_thumbstick(int thumbstick_x, int thumbstick_y, float* left_motor_speed, float* right_motor_speed);

void setup() {
    Serial.begin(115200);

    /**************************************************************
    *                     PCA9685 Servo Driver                    *
    **************************************************************/
    Serial.println("Initializing PCA9685");
    pca9685_connected = pca9685.begin();
    if (!pca9685_connected) {
        Serial.println("************> Initialization failed...");
    } else {
        pca9685.setOscillatorFrequency(PCA9685_OSCILLATION_FREQ); 
        pca9685.setPWMFreq(SERVO_FREQ_HZ);  // Analog servos run at ~50 Hz updates
    }
    

    /**************************************************************
    *                       PS3 Controller                        *
    **************************************************************/
    Serial.println("Initializing PS3 Controller...");
    Ps3.begin();
    Serial.println("Waiting for controller to connect...");
    while(!Ps3.isConnected()) {
        // Waiting...
        delay(100); // Not necessary, just prevents pinging isConnected() a ton
    }
    Serial.println("PS3 Controller connected!");


    /***************************************************************
    *                     DFMini Audio Driver                      *
    ***************************************************************/
    #ifdef ENABLE_AUDIO
    dfmp3.begin();
    dfmp3.reset(); // Could cause popping; can be removed after development.
    audio_num_tracks = dfmp3.getTotalTrackCount(DfMp3_PlaySource_Sd);
    dfmp3.setVolume(DEFAULT_AUDIO_VOLUME);
    if (STARTUP_TRACK_INDEX) {
        dfmp3.playMp3FolderTrack(STARTUP_TRACK_INDEX);
    }
    #endif
}

void loop() {

    // Map right thumbstick (for now) to head motors
    servo_neck_yaw_us = map(Ps3.data.analog.stick.lx, THUMBSTICK_MIN, THUMBSTICK_MAX, servo_min_us, servo_max_us);
    servo_neck_pitch_us = map(Ps3.data.analog.stick.ly, THUMBSTICK_MIN, THUMBSTICK_MAX, servo_min_us, servo_max_us);

    servo_neck_yaw_us = map(Ps3.data.analog.stick.lx, THUMBSTICK_MIN, THUMBSTICK_MAX, servo_min_us, servo_max_us);
    servo_neck_pitch_us = map(Ps3.data.analog.stick.ly, THUMBSTICK_MIN, THUMBSTICK_MAX, servo_min_us, servo_max_us);

    servo_eye_left_us = map(Ps3.event.analog_changed.button.l2, TRIGGER_MIN, TRIGGER_MAX, servo_min_us, servo_max_us);
    servo_eye_right_us = map(Ps3.event.analog_changed.button.r2, TRIGGER_MIN, TRIGGER_MAX, servo_min_us, servo_max_us);

    // Map thumbstick values to motor drive values
    map_thumbstick(Ps3.data.analog.stick.lx, -Ps3.data.analog.stick.ly, &left_motor_speed, &right_motor_speed);

    if (pca9685_connected) {
        motor_r.set_speed(right_motor_speed);
        motor_l.set_speed(left_motor_speed);
        motor_r.update();
        motor_l.update();
    }

    #ifdef ENABLE_AUDIO
    dfmp3.loop(); 
    dfmp3_status = dfmp3.getStatus();
    circle_pressed = Ps3.data.analog.button.circle;
    if (!circle_pressed_last && circle_pressed && (dfmp3_status.state != DfMp3_StatusState_Playing)) { 
        Serial.print("Playing Track #");
        Serial.println(audio_current_track + 1);
        dfmp3.playMp3FolderTrack(audio_current_track + 1); // +1 for 1 indexing of filenames
        audio_current_track = (audio_current_track + 1) % audio_num_tracks;
    }
    circle_pressed_last = circle_pressed;
    #endif

    // update dpad buttons and adjust the motor acceleration curve if pressed
    d_up_pressed = Ps3.data.analog.button.up;
    d_down_pressed = Ps3.data.analog.button.down;
    if (!d_up_pressed_last && d_up_pressed) {
        motor_speed_factor += 0.05;
        motor_r.set_speed_limit(motor_speed_factor);
        motor_l.set_speed_limit(motor_speed_factor);
        // motor_ramp_up_time_ms += 50;
        // motor_ramp_down_time_ms += 50;
        // motor_r.set_acceleration(motor_ramp_up_time_ms);
        // motor_l.set_acceleration(motor_ramp_up_time_ms);
        // motor_r.set_deceleration(motor_ramp_down_time_ms);
        // motor_l.set_deceleration(motor_ramp_down_time_ms);
    }
    if (!d_down_pressed_last && d_down_pressed) {
        motor_speed_factor -= 0.05;
        motor_r.set_speed_limit(motor_speed_factor);
        motor_l.set_speed_limit(motor_speed_factor);
        // motor_ramp_up_time_ms -= 50;
        // motor_ramp_down_time_ms -= 50;
        // motor_r.set_acceleration(motor_ramp_down_time_ms);
        // motor_l.set_acceleration(motor_ramp_down_time_ms);
        // motor_r.set_deceleration(motor_ramp_down_time_ms);
        // motor_l.set_deceleration(motor_ramp_down_time_ms);
    }
    d_up_pressed_last = d_up_pressed;
    d_down_pressed_last = d_down_pressed;



    // Debug printing
    static long last_update_time = 0;
    if (millis() - last_update_time > 500) {
        last_update_time = millis();
        // Serial.print("Motor ramp time: ");
        // Serial.println(motor_ramp_up_time_ms);
        Serial.print("left_motor_speed = ");
        Serial.println(left_motor_speed);
        Serial.print("motor_speed_factor = ");
        Serial.println(motor_speed_factor);
        // Serial.print("event.button_down = ");
        // Serial.println(Ps3.event.button_down.circle);
        // Serial.print("data.analog.button.circle = ");
        // Serial.println(Ps3.data.analog.button.circle, DEC);
        // Serial.print("calcul rmotor_us = ");
        // Serial.println(rmotor_us);
    }

}

/**
 * @brief Maps thumbstick input to motor thrust values.
 *
 * This function takes thumbstick input coordinates and maps them to motor thrust
 * values for a robotic system. It calculates the angle and magnitude of the input
 * and maps it to motor thrusts in four quadrants. Additionally, it allows for
 * reversing the direction of individual motors if needed.
 *
 * @param thumbstick_x The x-coordinate of the thumbstick input.
 * @param thumbstick_y The y-coordinate of the thumbstick input.
 * @param[out] lmotor_us Pointer to store the left motor pulse width value (microseconds).
 * @param[out] rmotor_us Pointer to store the right motor pulse width value (microseconds).
 */
void map_thumbstick(int thumbstick_x, int thumbstick_y, float* left_motor_speed, float* right_motor_speed) {
    // Calculate the angle and magnitude of the thumbstick input
    double theta = atan2(thumbstick_y, thumbstick_x);
    double r = sqrt(thumbstick_x * thumbstick_x + thumbstick_y * thumbstick_y) / ((double) -THUMBSTICK_MIN);

    // Ensure magnitude is within the valid range [0, 1]
    if (r > 1.0f) r = 1;

    double rmotor_thrust;
    double lmotor_thrust;

    // Map thumbstick input to motor thrusts in four quadrants
    if (theta >= 0.0 && theta <= HALF_PI) {
        // Quadrant 1
        rmotor_thrust = r * (theta - PI_OVER_FOUR) / PI_OVER_FOUR;
        lmotor_thrust = r;
    }
    if (theta > HALF_PI && theta <= PI) {
        // Quadrant 2
        rmotor_thrust = r;
        lmotor_thrust = r * (PI_OVER_FOUR - (theta - HALF_PI)) / PI_OVER_FOUR;
    }
    if (theta >= -PI && theta <= -HALF_PI) {
        // Quadrant 3
        rmotor_thrust = r * (-(theta + HALF_PI) - PI_OVER_FOUR) / PI_OVER_FOUR;
        lmotor_thrust = -r;
    }
    if (theta > -HALF_PI && theta < 0.0) {
        // Quadrant 4
        rmotor_thrust = -r;
        lmotor_thrust = r * (theta + HALF_PI - PI_OVER_FOUR) / PI_OVER_FOUR;
    }

    // Reverse motor directions if specified
    #ifdef MOTOR_RIGHT_REVERSE_DIRECTION
        rmotor_thrust *= -1;
    #endif
    #ifdef MOTOR_LEFT_REVERSE_DIRECTION
        lmotor_thrust *= -1;
    #endif

    // Calculate motor pulse width values and store them
    *right_motor_speed = rmotor_thrust;
    *left_motor_speed = lmotor_thrust;
}


class Mp3Notify
{
public:
    static void PrintlnSourceAction(DfMp3_PlaySources source, const char* action) {
        if (source & DfMp3_PlaySources_Sd) {
            Serial.print("SD Card, ");
        }
        if (source & DfMp3_PlaySources_Usb) {
            Serial.print("USB Disk, ");
        }
        if (source & DfMp3_PlaySources_Flash) {
            Serial.print("Flash, ");
        }
        Serial.println(action);
    }

    static void OnError([[maybe_unused]] DfMp3& mp3, uint16_t errorCode)
    {
        // see DfMp3_Error for code meaning
        Serial.println();
        Serial.print("Com Error ");
        Serial.println(errorCode);
    }

    static void OnPlayFinished([[maybe_unused]] DfMp3& mp3, [[maybe_unused]] DfMp3_PlaySources source, uint16_t track) {
        Serial.print("Play finished for #");
        Serial.println(track);  
    }

    static void OnPlaySourceOnline([[maybe_unused]] DfMp3& mp3, DfMp3_PlaySources source) {
        PrintlnSourceAction(source, "online");
    }

    static void OnPlaySourceInserted([[maybe_unused]] DfMp3& mp3, DfMp3_PlaySources source) {
        PrintlnSourceAction(source, "inserted");
    }

    static void OnPlaySourceRemoved([[maybe_unused]] DfMp3& mp3, DfMp3_PlaySources source) {
        PrintlnSourceAction(source, "removed");
    }
};

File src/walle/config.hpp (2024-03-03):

/**
 * @file config.h
 * @brief Configuration file for Wall-E robot.
 *
 * This file contains the configuration settings for Wall-E.
 * Modify the values in this file to setup or customize the behavior of WALL-E.
 *
 * @date 01/21/2024
 * @version 0.1
 */

#ifndef CONFIG_HPP
#define CONFIG_HPP


/*---- Motor Index Mapping --------------------------------------------
*  The following constants are used to map the servo motors to the
*  corresponding index of the PWM module. The index is printed on the
*  silkscreen of the module.
*  -------------------------------------------------------------------*/
// Drive motors
#define MOTOR_RIGHT_IDX (0)
#define MOTOR_LEFT_IDX  (1)

// Arm servos
#define SERVO_SHOULDER_RIGHT_IDX (2)
#define SERVO_SHOULDER_LEFT_IDX  (3)

#define SERVO_ELBOW_RIGHT_IDX (4)
#define SERVO_ELBOW_LEFT_IDX  (5)

#define SERVO_WRIST_RIGHT_IDX (6)
#define SERVO_WRIST_LEFT_IDX  (7)

#define SERVO_HAND_RIGHT_IDX  (8)
#define SERVO_HAND_LEFT_IDX   (9)

// Head servos
#define SERVO_NECK_PITCH_IDX  (14)
#define SERVO_NECK_YAW_IDX    (15)
                        
#define SERVO_EYE_RIGHT_IDX   (12)
#define SERVO_EYE_LEFT_IDX    (13)

/*---- Track Motor Configs --------------------------------------------
*  The following constants setup parameters for the track motors.
*  -------------------------------------------------------------------*/
typedef struct TrackVelocityProfile{
    float speed_scaler;
    float acceleration;
} TrackVelocityProfile_t;

const TrackVelocityProfile_t TRACK_VELOCITY_PROFILES[] = {
    { .speed_scaler = 0.4, .acceleration = 1.25 }, // Slow
    { .speed_scaler = 0.5, .acceleration = 1.50 }, // Normal
    { .speed_scaler = 0.6, .acceleration = 2.00 }, // Fast
};
#define TRACK_VELOCITY_DEFAULT_PROFILE_IDX (1) // Index of the default velocity profile

/*---- Servo Head Motor Configs ---------------------------------------
*  The following constants setup phyiscal parameters of the servo 
*  motors. These should typically be configured and set once. 
*  -------------------------------------------------------------------*/
// Set the min and max us for the neck servos
#define SERVO_NECK_YAW_MAX_US (2500)
#define SERVO_NECK_YAW_MIN_US (700)
#define SERVO_NECK_YAW_NEUTRAL_US (1500)

#define SERVO_NECK_PITCH_MAX_US (1800)
#define SERVO_NECK_PITCH_MIN_US (1200)
#define SERVO_NECK_PITCH_NEUTRAL_US (1500)

// Set the min and max us for the arm servos
#define SERVO_SHOULDER_MAX_US (2000)
#define SERVO_SHOULDER_MIN_US (1000)
#define SERVO_SHOULDER_NEUTRAL_US (1500)

#define SERVO_ELBOW_MAX_US (2000)
#define SERVO_ELBOW_MIN_US (1000)
#define SERVO_ELBOW_NEUTRAL_US (1500)

#define SERVO_WRIST_MAX_US (2000)
#define SERVO_WRIST_MIN_US (1000)
#define SERVO_WRIST_NEUTRAL_US (1500)

#define SERVO_HAND_MAX_US (2000)
#define SERVO_HAND_MIN_US (1000)
#define SERVO_HAND_NEUTRAL_US (1500)

// Set the min and max us for the eye servos
#define SERVO_EYE_RIGHT_MAX_US (2000)
#define SERVO_EYE_RIGHT_MIN_US (1000)
#define SERVO_EYE_RIGHT_NEUTRAL_US (1500)

#define SERVO_EYE_LEFT_MAX_US (2000)
#define SERVO_EYE_LEFT_MIN_US (1000)
#define SERVO_EYE_LEFT_NEUTRAL_US (1500)

// Uncomment a line to reverse the direction of the track motor
// #define MOTOR_RIGHT_REVERSE_DIRECTION
// #define MOTOR_LEFT_REVERSE_DIRECTION

/*---- Audio Player Settings -------------------------------------------
*  Various settings of the Audio Player module.
*  -------------------------------------------------------------------*/
#define DEFAULT_AUDIO_VOLUME (24) // NOTE: Max volume is 30

// Index of audio tracks by their numbering on the SD card
#define TRACK_INDEX_STARTUP  (1)
#define TRACK_INDEX_EVE_1    (2)
#define TRACK_INDEX_SCREAM   (3)
#define TRACK_INDEX_EVE_2    (4)
#define TRACK_INDEX_TADA     (5)
#define TRACK_INDEX_EVE_3    (6)
#define TRACK_INDEX_WALLE_1  (7)
#define TRACK_INDEX_EVE_4    (8)
#define TRACK_LA_VIE_EN_ROSE (9)
#define TRACK_DEFINE_DANCING (10)

// The track index to play on WALL-E startup
#define AUDIO_STARTUP_TRACK (TRACK_INDEX_STARTUP) // NOTE: Set to 0 if you don't want to play anything

// Tracks in this array will be selected randomly by the playRandomTrack() function
const int audio_track_random_list[] = {
    TRACK_INDEX_EVE_1,
    TRACK_INDEX_EVE_2,
    TRACK_INDEX_EVE_3,
    TRACK_INDEX_WALLE_1,
    TRACK_INDEX_SCREAM,
    TRACK_INDEX_TADA,
};

// List of tracks to bind to controller buttons. Primary controller L2 provides an additional 4 options. The order is: 
// 0: up
// 1: right
// 2: down
// 3: left
// 4: L2 + up
// 5: L2 + right
// 6: L2 + down
// 7: L2 + left
const int audio_track_selection_list[] = {
    TRACK_INDEX_EVE_1, // Up
    TRACK_INDEX_TADA, // Right
    TRACK_INDEX_SCREAM, // Down
    TRACK_INDEX_WALLE_1, // Left
    TRACK_INDEX_EVE_2, // L2 + Up
    TRACK_INDEX_EVE_3, // L2 + Right
    TRACK_DEFINE_DANCING, // L2 + Down
    TRACK_LA_VIE_EN_ROSE, // L2 + Left
};
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

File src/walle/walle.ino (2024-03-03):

/**
 * @file walle.ino
 * @author Isaac Rex (@Acliad)
 * @brief Main program file for the Wall-E robot.
 * @version 0.1
 * @date 2023-10-08
 *
 * @copyright Copyright (c) 2023
 *
 */

#include "walle.hpp"

/**************************************************************
 *                         Constants                          *
 **************************************************************/
/*----------- PCA9685 PWM Module -------------------------*/
const unsigned int PCA9685_OSCILLATION_FREQ = 25000000;
const unsigned int SERVO_FREQ_HZ = 50; // NOTE: Analog servos run at ~50 Hz updates

/*----------- Controllers --------------------------------*/
const unsigned int MAX_NUM_GAMEPADS = 2;

/*----------- Buttons ------------------------------------*/
const unsigned int BUTTON_PIN_RECORD = 32;
const unsigned int BUTTON_PIN_PLAY = 35;
const unsigned int BUTTON_PIN_STOP = 34;
const unsigned int BUTTON_PIN_SUN = 33;

/*----------- Animations ---------------------------------*/
const char *ANIMATION_FILE_FORMATTER = "/animation_%d.txt";
const int   ANIMATION_FILE_STRING_BUFFER_SIZE = 30;

/**************************************************************
 *                         Variables                          *
 **************************************************************/
/*----------- Display ------------------------------------*/
TFT_eSPI tft = TFT_eSPI();
Display  display = Display(tft);

/*----------- PCA9685 PWM Module -------------------------*/
bool                    pca9685_connected = false;
Adafruit_PWMServoDriver pca9685 = Adafruit_PWMServoDriver();

/*----------- Track Motors -------------------------------*/
float left_motor_speed = 0.0f;
float right_motor_speed = 0.0f;

int track_velocity_profile_idx = TRACK_VELOCITY_DEFAULT_PROFILE_IDX;
// NOTE: The motor constructor assumes the PCA9685 has already been initialized
DriveMotor motor_r = DriveMotor(&pca9685, MOTOR_RIGHT_IDX);
DriveMotor motor_l = DriveMotor(&pca9685, MOTOR_LEFT_IDX);

/*----------- Head Servos --------------------------------*/
float neck_yaw_position = 0.0f;
float neck_pitch_position = 0.0f;
float eye_left_position = 0.0f;
float eye_right_position = 0.0f;

// NOTE: Initializing with default parameters here, updated in initServos()
ServoMotor servo_neck_yaw(&pca9685, SERVO_NECK_YAW_IDX, SERVO_NECK_YAW_NAME);
ServoMotor servo_neck_pitch(&pca9685, SERVO_NECK_PITCH_IDX, SERVO_NECK_PITCH_NAME);
ServoMotor servo_eye_left(&pca9685, SERVO_EYE_LEFT_IDX, SERVO_EYE_LEFT_NAME);
ServoMotor servo_eye_right(&pca9685, SERVO_EYE_RIGHT_IDX, SERVO_EYE_RIGHT_NAME);

/*----------- Arm Servos ---------------------------------*/
float shoulder_left_position = 0.0f;
float shoulder_right_position = 0.0f;
float elbow_left_position = 0.0f;
float elbow_right_position = 0.0f;
float wrist_left_position = 0.0f;
float wrist_right_position = 0.0f;
float hand_left_position = 0.0f;
float hand_right_position = 0.0f;

ServoMotor servo_shoulder_left(&pca9685, SERVO_SHOULDER_LEFT_IDX, SERVO_SHOULDER_LEFT_NAME);
ServoMotor servo_shoulder_right(&pca9685, SERVO_SHOULDER_RIGHT_IDX, SERVO_SHOULDER_RIGHT_NAME);
ServoMotor servo_elbow_left(&pca9685, SERVO_ELBOW_LEFT_IDX, SERVO_ELBOW_LEFT_NAME);
ServoMotor servo_elbow_right(&pca9685, SERVO_ELBOW_RIGHT_IDX, SERVO_ELBOW_RIGHT_NAME);
ServoMotor servo_wrist_left(&pca9685, SERVO_WRIST_LEFT_IDX, SERVO_WRIST_LEFT_NAME);
ServoMotor servo_wrist_right(&pca9685, SERVO_WRIST_RIGHT_IDX, SERVO_WRIST_RIGHT_NAME);
ServoMotor servo_hand_left(&pca9685, SERVO_HAND_LEFT_IDX, SERVO_HAND_LEFT_NAME);
ServoMotor servo_hand_right(&pca9685, SERVO_HAND_RIGHT_IDX, SERVO_HAND_RIGHT_NAME);

ServoContext servo_context;

/*----------- Audio Player -------------------------------*/
unsigned int audio_current_track = 0;
unsigned int audio_num_tracks = 1;
DfMp3        dfmp3 = DfMp3(Serial2);

/*----------- Controllers/Buttons -------------------------*/
GamepadPtr           myGamepads[MAX_NUM_GAMEPADS];
NavigationController drive_controller;
NavigationController aux_controller;
// Keep an array of NavigationControllers to make connecting/disconnecting easier
NavigationController *controllers[MAX_NUM_GAMEPADS] = {&drive_controller, &aux_controller};

// Buttons
Button button_record = Button(BUTTON_PIN_RECORD, BUTTON_DEBOUNCE_TIME_MS);
Button button_play = Button(BUTTON_PIN_PLAY, BUTTON_DEBOUNCE_TIME_MS);
Button button_stop = Button(BUTTON_PIN_STOP, BUTTON_DEBOUNCE_TIME_MS);
Button button_sun = Button(BUTTON_PIN_SUN, BUTTON_DEBOUNCE_TIME_MS); // Used as a reset button

Button *buttons[] = {&button_record, &button_play, &button_stop, &button_sun};

/*----------- General ------------------------------------*/
enum class WallEState {
    NORMAL,
    RECORDING_NEW,
    RECORDING_EDIT
};
WallEState              state = WallEState::NORMAL;
ServoAnimationRecorder *servo_recorder = nullptr;
Stats                   loop_stats = Stats(0.99);
const int               DPAD_UP_INDEX = 0;
const int               DPAD_RIGHT_INDEX = 1;
const int               DPAD_DOWN_INDEX = 2;
const int               DPAD_LEFT_INDEX = 3;
const int               ANIMATION_MODIFIER_OFFSET = 4;
// TODO: The current code is such that these animations get deleted when that slot is overwritten. This generally works
// for dynamically allocated animations, but it causes a crash on statically allocated animations. I.e., the ones
// defined at compile time like cock_left, wiggle_eyes, etc. You can still overwrite these and the new recording will 
// stick, it will just crash and reboot.
ServoAnimation         *head_animations[] = {
    nullptr, // Up
    nullptr, // Right
    nullptr, // Down
    nullptr, // Left
    nullptr, // L2 + Up
    nullptr, // L2 + Right
    nullptr, // L2 + Down
    nullptr  // L2 + Left
};
ServoPlayer &servo_player = ServoPlayer::getInstance();

/**************************************************************
 *                    Function Prototypes                     *
 **************************************************************/
/*----------- Controllers --------------------------------*/
bool isGamepadConnected();
void mapThumbstick(int thumbstick_x, int thumbstick_y, float *left_motor_speed, float *right_motor_speed);
void mapInputs(float dt);

/*----------- Audio Player -------------------------------*/
void playRandomTrack();

/*----------- General ------------------------------------*/
void updateAll();
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

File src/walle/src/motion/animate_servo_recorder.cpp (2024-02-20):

/**
 * @file animate_servo_recorder.cpp
 * @author Isaac Rex (@Acliad)
 * @brief This file contains the implementation of the ServoAnimationRecorder class, which is used to record servo
 * animations.
 * @version 0.1
 * @date 2024-02-19
 * 
 * @copyright Copyright (c) 2024
 * 
 */
#include "animate_servo_recorder.hpp"

ServoAnimationRecorder::ServoAnimationRecorder(Display &display, ServoContext &servo_context)
    : _state(States::ENTRY), _animation(new ServoAnimation()), _display(display),
      _display_start_mode(display.getMode()), _keyframe_num(0), _servos(servo_context),
      _current_keyframe(new ServoKeyframe(_DEFAULT_KEYFRAME_LENGTH_MS)), _cursor_position(_DEFAULT_CURSOR_POSITION),
      _servo_player(ServoPlayer::getInstance()), _cycle_animation(nullptr) {

    _display.setMode(Display::Mode::RECORDER);
    _display.recording_panel.setStartPage();

    // Add the initial (head) keyframe to this animation
    _animation->set_head(_current_keyframe);
}

ServoAnimationRecorder::~ServoAnimationRecorder() {
    _display.setMode(_display_start_mode);

    // Delete the animation (and bound keyframes) if the animation was not taken
    if (_animation != nullptr) {
        delete _animation;
    }

    // Make sure the servo player isn't trying to play the cycle animation
    if (_servo_player.getCurrentAnimation() == _cycle_animation) {
        _servo_player.stop();
    }
    // Delete the cycle animation if it exists
    if (_cycle_animation != nullptr) {
        delete _cycle_animation;
    }
}

ServoAnimationRecorder::States ServoAnimationRecorder::inputEvent(Inputs input) {
    switch (_state) {
    case States::ENTRY:
        if (input == Inputs::UP || input == Inputs::DOWN || input == Inputs::LEFT || input == Inputs::RIGHT) {
            _updateRecordingStateDisplay();
            _state = States::RECORDING;
        } else if (input == Inputs::CANCEL) {
            _display.recording_panel.setCancelPage();
            _state = States::CANCEL;
        }
        break;
    case States::RECORDING:
        if (input == Inputs::DONE) {
            _display.recording_panel.setSavePage();
            _state = States::SAVE;
        } else if (input == Inputs::CANCEL) {
            _display.recording_panel.setCancelPage();
            _state = States::CANCEL;
        } else {
            _handleRecordingInput(input);
        }
        break;
    case States::SAVE:
        if (input == Inputs::DONE) {
            _saveCurrentKeyframeServos();
            _display.setMode(_display_start_mode);
            _state = States::DONE;
        } else {
            _updateRecordingStateDisplay();
            _state = States::RECORDING;
        }
        break;
    case States::CANCEL:
        if (input == Inputs::CANCEL) {
            delete _animation;
            _animation = nullptr;
            _display.setMode(_display_start_mode);
            _state = States::DONE;
        }
        else {
            _updateRecordingStateDisplay();
            _state = States::RECORDING;
        }
        break;
    }
    return _state;
}

ServoAnimationRecorder::States ServoAnimationRecorder::getState() {
    return _state;
}

ServoAnimation *ServoAnimationRecorder::takeAnimation() {
    if (_state != States::DONE) {
        return nullptr;
    }
    ServoAnimation *ret = _animation;
    _animation = nullptr;
    _current_keyframe = nullptr;
    return ret;
}

void ServoAnimationRecorder::setAnimation(ServoAnimation *animation) {
    if (_animation != nullptr) {
        delete _animation;
    }
    _animation = new ServoAnimation(*animation);
    _current_keyframe = _animation->get_head();
    _keyframe_num = 0;
    _cursor_position = _DEFAULT_CURSOR_POSITION;
    _moveServosToCurrentKeyframe();
}

void ServoAnimationRecorder::addTrackToKeyframe(int track_index, DfMp3 *dfmp3) {
    if (_current_keyframe != nullptr) {
        _current_keyframe->add_track(track_index, dfmp3);
    }
}

void ServoAnimationRecorder::_updateRecordingStateDisplay() {
    _display.recording_panel.setRecordingPage(_current_keyframe->get_duration(), _cursor_position, _keyframe_num,
                                              &_servos);
}

void ServoAnimationRecorder::_handleRecordingInput(Inputs input) {

    switch (input) {
    case Inputs::UP:
    case Inputs::DOWN:
    case Inputs::LEFT:
    case Inputs::RIGHT:
        _updateKeyframeDuration(input);
        break;
    case Inputs::NEXT:
        _goToNextKeyframe();
        break;
    case Inputs::PREV:
        _goToPrevKeyframe();
        break;
    case Inputs::DELETE:
        _deleteCurrentKeyframe();
    default:
        return;
    }

    // Update the display
    _updateRecordingStateDisplay();
}

void ServoAnimationRecorder::_goToNextKeyframe() {
    _saveCurrentKeyframeServos(); // Update the current keyframe's servos in case they were moved
    // If the current keyframe has a next keyframe, move to it. Otherwise, create a new keyframe
    if (_current_keyframe->get_next() != nullptr) {
        _current_keyframe = _current_keyframe->get_next();
        _moveServosToCurrentKeyframe();
    } else {
        // We were already at the tail, so create a new keyframe
        ServoKeyframe *new_keyframe = new ServoKeyframe(_DEFAULT_KEYFRAME_LENGTH_MS);
        _current_keyframe->set_next(new_keyframe);
        new_keyframe->set_prev(_current_keyframe);
        _current_keyframe = new_keyframe;
    }
    _keyframe_num++;
}

void ServoAnimationRecorder::_goToPrevKeyframe() {
    _saveCurrentKeyframeServos(); // Update the current keyframe's servos in case they were moved
    // If the current keyframe has a previous keyframe, move to it
    if (_current_keyframe->get_prev() != nullptr) {
        // Move to the previous keyframe
        _current_keyframe = _current_keyframe->get_prev();
        _keyframe_num--;
        _moveServosToCurrentKeyframe();
    }
}

void ServoAnimationRecorder::_deleteCurrentKeyframe() {
    // Remove the current keyframe from the animtion. Defaults to going to the next keyframe if it exists, otherwise
    // the previous keyframe
    ServoKeyframe *to_delete = _current_keyframe;

    // If there is another keyframe after this one, move to it
    if (_current_keyframe->get_next() != nullptr) {
        _goToNextKeyframe();
        _keyframe_num--; // Next keyframe is now the current keyframe, so decrement the keyframe number
    } else if (_current_keyframe->get_prev() != nullptr) { // If there is another keyframe before this one, move to it
        _goToPrevKeyframe();
    } else { // If there are no other keyframes, we're at the head and we can't delete it
        return;
    }

    // If we removed the head, set the new head
    if (to_delete == _animation->get_head()) {
        _animation->set_head(_current_keyframe);
    }
    // Remove the keyframe from the animation
    delete to_delete; // NOTE: The deconstructor for ServoKeyframe will restitch the list
    _updateRecordingStateDisplay();
}
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

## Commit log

2023-10-08 Checkpoint before deleting motor.hpp/.cpp files
    Decided to go for a single class approach for the motor and another for the servos. At least for now. Cleaning up, but wanted to maintain the files in case I decide to go back.
2024-01-21 Brought in display, updated controller, motor/servo code. Cleaned up
2024-01-21 Added PCBs and inital mechanical files
    [Board Outline.dxf, Carrier Board Standoff.stl, Carrier Board Standoff.stp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]
2024-01-27 Cleaned PCB folder
2024-01-28 Added PDF of carrier board schematic
2024-01-28 Removed output directory from arduino.json
2024-01-28 Added class for buttons
2024-01-28 Added note to schematic about button pullups
    [WALL-E Carrier Board.kicad_sch]
2024-02-04 Added thumbsticks buttons to NavigationController class
2024-02-04 Moved updating of motor speed from mapInputs() to updateAll()
2024-02-11 Updated thickness of button inserts to 0.4mm
    [Play Button.stl, Play Button.stp, Play Insert.stl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]
2024-02-11 Added servo recorder. Still has some memory leaks
    [animate_servo.cpp, animate_servo_recorder.cpp, animate_servo_recorder.hpp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]
2024-02-11 Fix attempt for Bluetooth connection bug in gamepad controller
    [walle.ino]
2024-02-16 Added track saving and loading, moved MP3Notify to own class
2024-02-16 Added picture of buttons for reference
2024-02-18 Edit ServoAnimation mode added, changed ServoContext to a map
2024-02-28 Updated standoff 3D model
    [Carrier Board Standoff.stp]
2024-03-03 Moved readme.md to root, updated button map image
